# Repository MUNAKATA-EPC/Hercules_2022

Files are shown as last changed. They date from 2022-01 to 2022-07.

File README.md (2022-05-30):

# Hercules_2022

ヘラクレス2022シーズンのソースコード、基板データを公開しています。

詳しくはWikiを参照。

## 運用方針

- 大きな変更をするときはブランチを絶対に別途作成しましょう
- 小さな変更(スペルミスやコメント修正程度)ならどんどんmainブランチに突っ込んでもまあ構わないでしょう
- 余裕があったら変更した内容をコメントしてくれると助かります

## コードに関して

- 各プロジェクトフォルダの命名規則は「hogehoge(プロジェクト名)-teensy40(開発環境名)」となっていますが、一部試験用に作ったものに関しては、この命名規則が守られておりません...ごめんなさい。
- プロジェクトフォルダ内の「src」フォルダ内にmain.cpp(一部プロジェクトは名称が異なります)、「lib」フォルダ内に各種ライブラリ、「include」フォルダ内にサブプログラムが入っています。
- 一部PlatformIOからダウンロードしているライブラリが含まれているため、基本は「VSCode + PlatformIO」の組み合わせでご覧ください。

## 回路に関して

- 使用する設計ソフトにKiCad5と6が混在しています。
- ライブラリについてはLibraryフォルダを相対パスで参照しています。
- 発注は主にJLCPCBを使用します。

## 開発環境に関して

- VSCodeの拡張機能のPlatformIOを使用しTeensy 4.0とSeeeduino XIAOに書き込んでいます。
- 弊チームにはMacユーザーがいないため、Windows環境での開発を想定しております。Macをお使いの皆様、何か問題が生じても対応はできません。予めご了承ください。

## ライセンスに関して

- すべてのコード、基板データに関するライセンスはMITにしていますが、ライブラリ等のライセンスはそのライブラリごとのライセンスに従ってください。

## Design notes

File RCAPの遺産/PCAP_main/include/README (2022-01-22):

This directory is intended for project header files.

A header file is a file containing C declarations and macro definitions
to be shared between several project source files. You request the use of a
header file in your project source file (C, C++, etc) located in `src` folder
by including it, with the C preprocessing directive `#include'.

このディレクトリは、プロジェクトヘッダーファイル用です。

ヘッダーファイルは、C宣言とマクロ定義を含むファイルです。
複数のプロジェクトソースファイル間で共有されます。 あなたはの使用を要求します
`src`フォルダにあるプロジェクトソースファイル（C、C ++など）のヘッダーファイル
C前処理ディレクティブ `#include 'を使用してインクルードします。

```src/main.c

#include "header.h"

int main (void)
{
 ...
}
```
Including a header file produces the same results as copying the header file
into each source file that needs it. Such copying would be time-consuming
and error-prone. With a header file, the related declarations appear
in only one place. If they need to be changed, they can be changed in one
place, and programs that include the header file will automatically use the
new version when next recompiled. The header file eliminates the labor of
finding and changing all the copies as well as the risk that a failure to
find one copy will result in inconsistencies within a program.

ヘッダーファイルをインクルードすると、ヘッダーファイルをコピーした場合と同じ結果が得られます。
それを必要とする各ソースファイルに。 このようなコピーには時間がかかります
エラーが発生しやすい。 ヘッダーファイルを使用すると、関連する宣言が表示されます
一箇所だけで。 変更が必要な場合は、一度に変更できます
場所、およびヘッダーファイルを含むプログラムは自動的にを使用します
次に再コンパイルされたときの新しいバージョン。 ヘッダーファイルはの労力を排除します
すべてのコピーを見つけて変更するだけでなく、失敗するリスク
1つのコピーを見つけると、プログラム内で不整合が発生します。

In C, the usual convention is to give header files names that end with `.h'.
It is most portable to use only letters, digits, dashes, and underscores in
header file names, and at most one dot.

Cでは、通常の規則は、ヘッダーファイルに `.h 'で終わる名前を付けることです。
文字、数字、ダッシュ、およびアンダースコアのみを使用するのが最も移植性があります
ヘッダーファイル名、および最大1つのドット。

Read more about using header files in official GCC documentation:

* Include Syntax
* Include Operation
* Once-Only Headers
* Computed Includes

https://gcc.gnu.org/onlinedocs/cpp/Header-Files.html

s公式GCCドキュメントでヘッダーファイルの使用について詳しく読む：

*構文を含める
*操作を含める
* 1回限りのヘッダー
*計算されたインクルード

https://gcc.gnu.org/onlinedocs/cpp/Header-Files.html

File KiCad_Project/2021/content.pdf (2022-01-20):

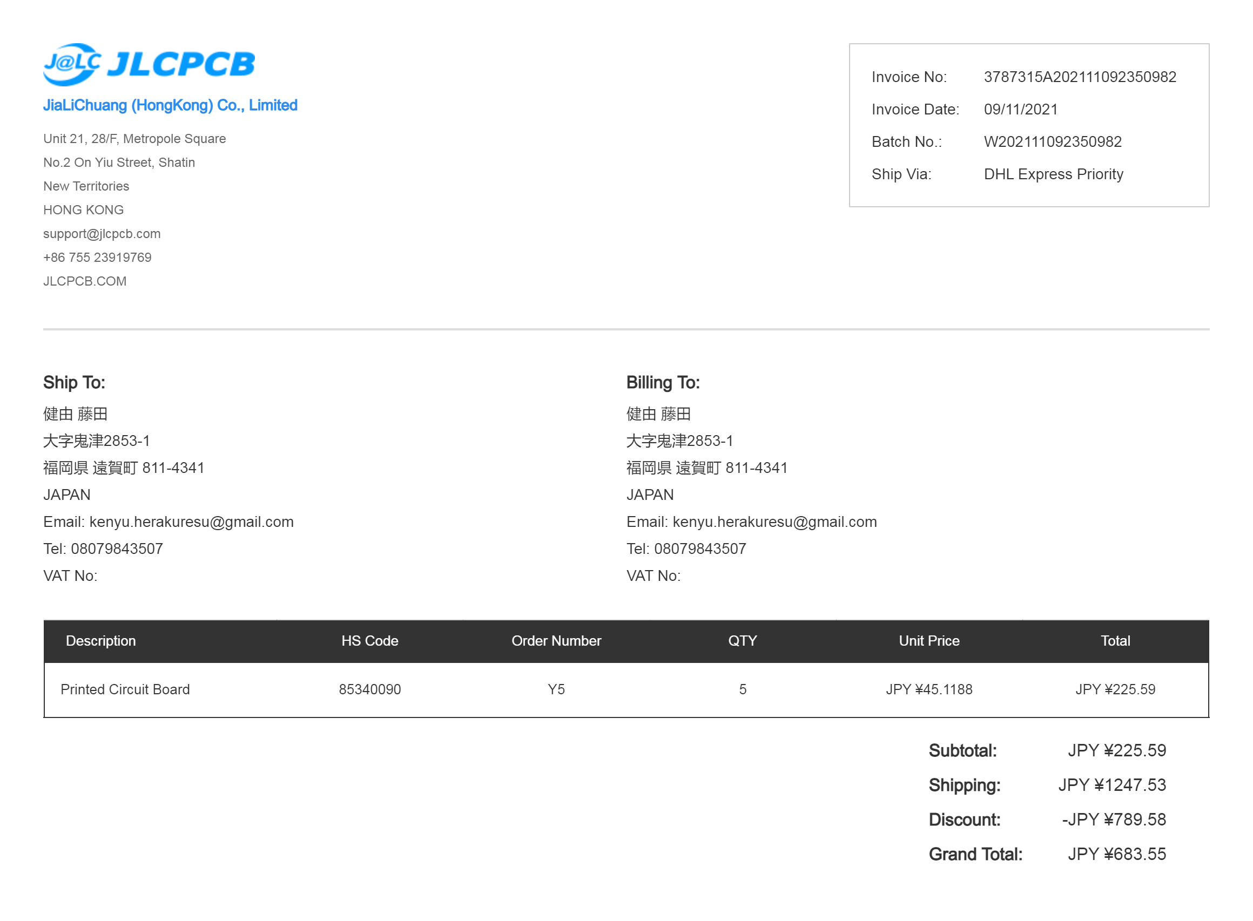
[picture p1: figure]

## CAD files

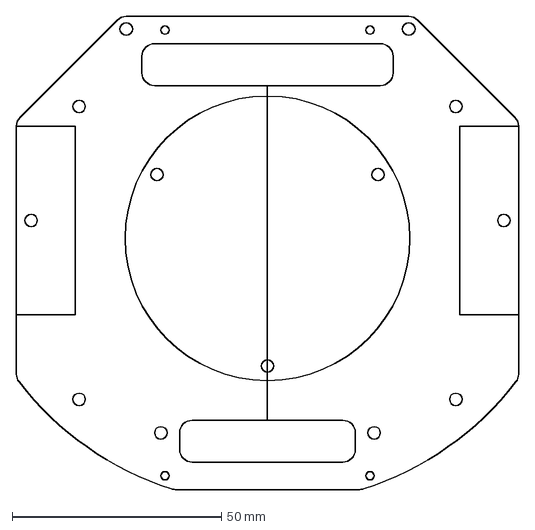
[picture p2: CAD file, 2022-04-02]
KiCad_Project/2022/DXF/Main_Board_2.dxf
120.0 x 113.0 mm

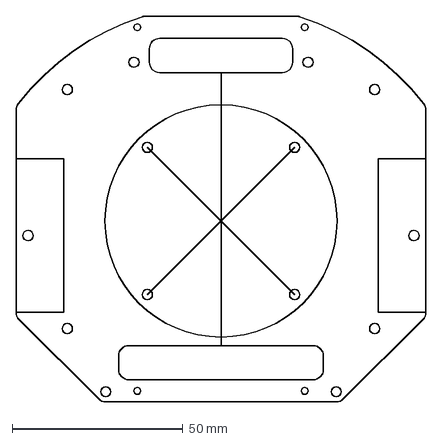
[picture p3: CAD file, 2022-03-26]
KiCad_Project/2022/DXF/Main_Board.dxf
120.0 x 113.0 mm

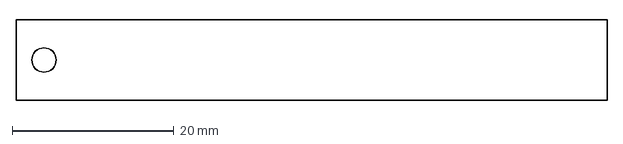
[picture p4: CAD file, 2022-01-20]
KiCad_Project/2021/DXF/LINE_2.dxf
73.0 x 10.0 mm

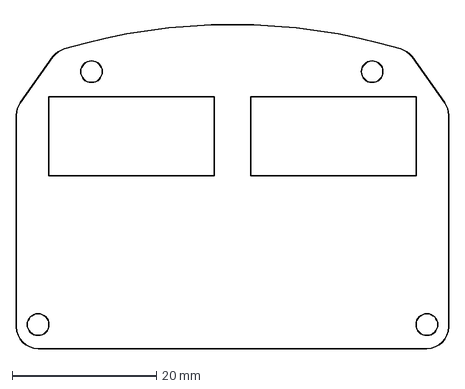
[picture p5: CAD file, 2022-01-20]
KiCad_Project/2021/電源基板.dxf
60.0 x 46.1 mm

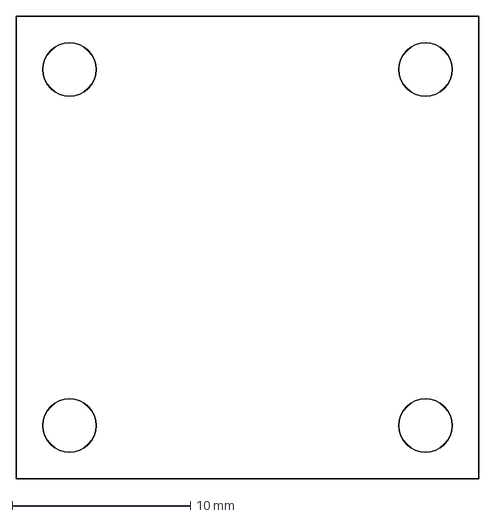
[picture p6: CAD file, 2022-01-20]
KiCad_Project/2021/DXF/LINE_1.dxf
26.0 x 26.0 mm

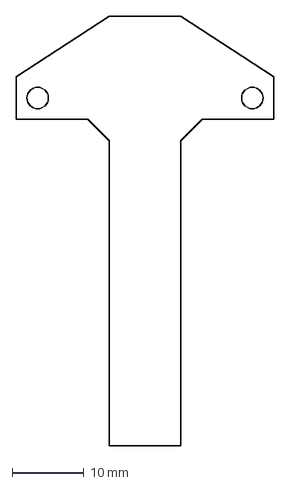
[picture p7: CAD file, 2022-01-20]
KiCad_Project/2021/DXF/LINE_4.dxf
36.0 x 60.0 mm

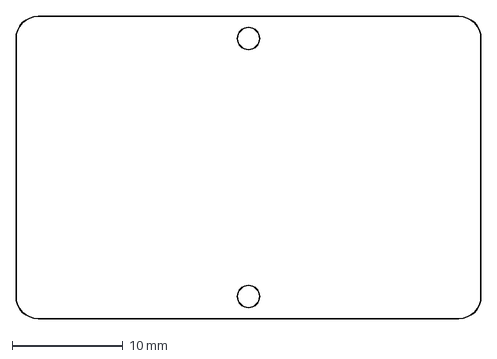
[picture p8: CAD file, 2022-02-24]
KiCad_Project/2022/DXF/ADNS-9800.dxf
42.0 x 27.3 mm

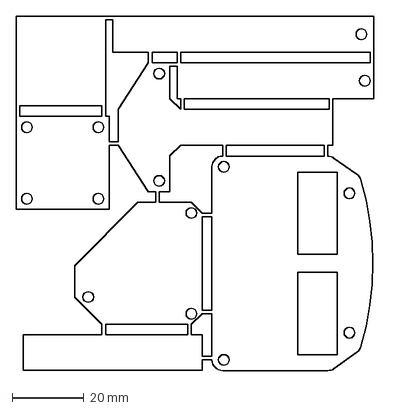
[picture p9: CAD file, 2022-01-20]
KiCad_Project/2021/DXF/発注基板 v1.dxf
100.9 x 99.1 mm

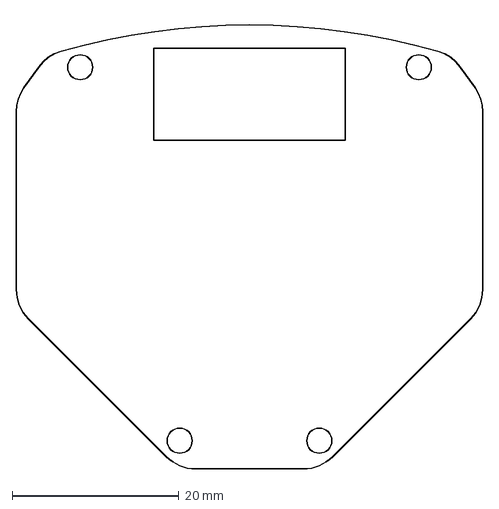
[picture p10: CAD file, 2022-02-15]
KiCad_Project/2022/DXF/Integrated_Power_Board.dxf
56.0 x 54.4 mm

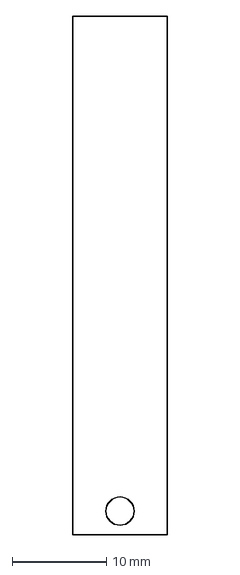
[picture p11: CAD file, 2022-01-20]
KiCad_Project/2021/DXF/LINE_3.dxf
10.0 x 55.0 mm

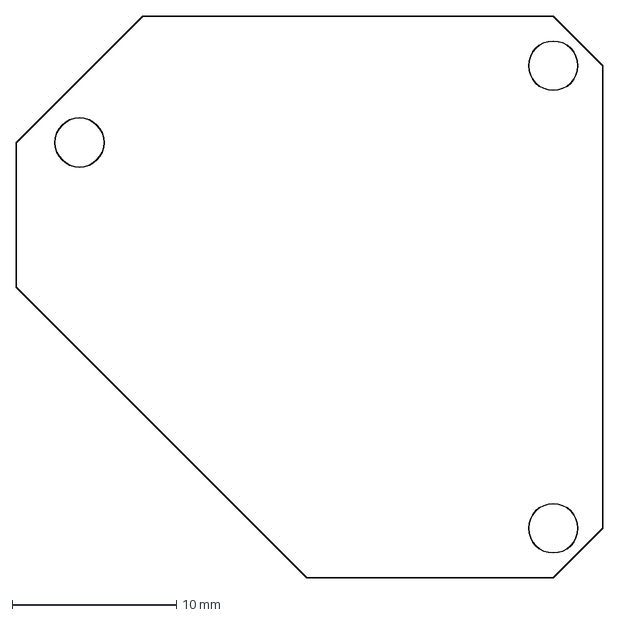
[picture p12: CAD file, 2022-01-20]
KiCad_Project/2021/DXF/kick.dxf
35.7 x 34.2 mm

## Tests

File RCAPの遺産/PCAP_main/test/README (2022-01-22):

This directory is intended for PlatformIO Unit Testing and project tests.

Unit Testing is a software testing method by which individual units of
source code, sets of one or more MCU program modules together with associated
control data, usage procedures, and operating procedures, are tested to
determine whether they are fit for use. Unit testing finds problems early
in the development cycle.

このディレクトリは、PlatformIOユニットテストおよびプロジェクトテストを対象としています。
ユニットテストは、ソースコードの個々のユニット、関連する制御データ、使用手順、および操作手順とともに1つ以上のMCUプログラムモジュールのセットによるソフトウェアテスト方法であり、
それらが使用に適しているかどうかを判断するためにテストされます。 
単体テストでは、開発サイクルの早い段階で問題が見つかります。

More information about PlatformIO Unit Testing:
- https://docs.platformio.org/page/plus/unit-testing.html

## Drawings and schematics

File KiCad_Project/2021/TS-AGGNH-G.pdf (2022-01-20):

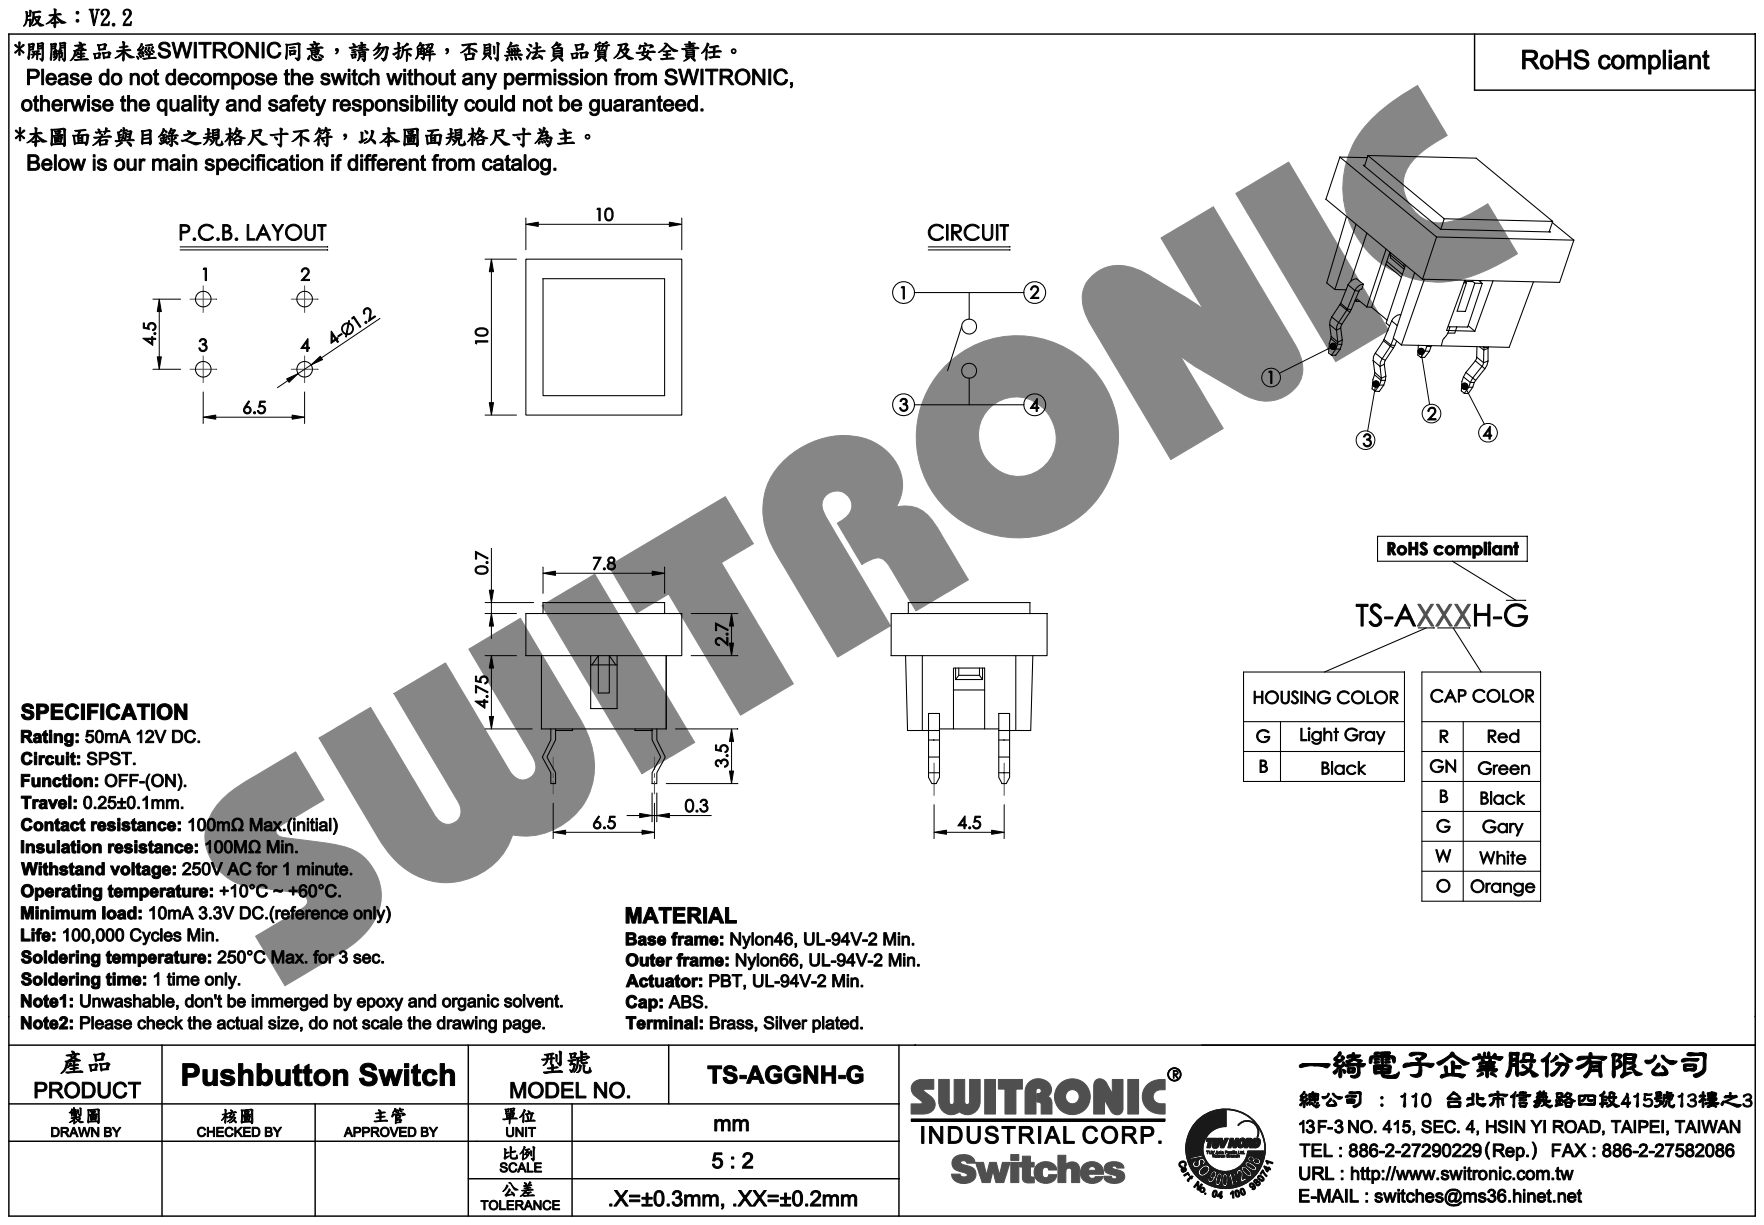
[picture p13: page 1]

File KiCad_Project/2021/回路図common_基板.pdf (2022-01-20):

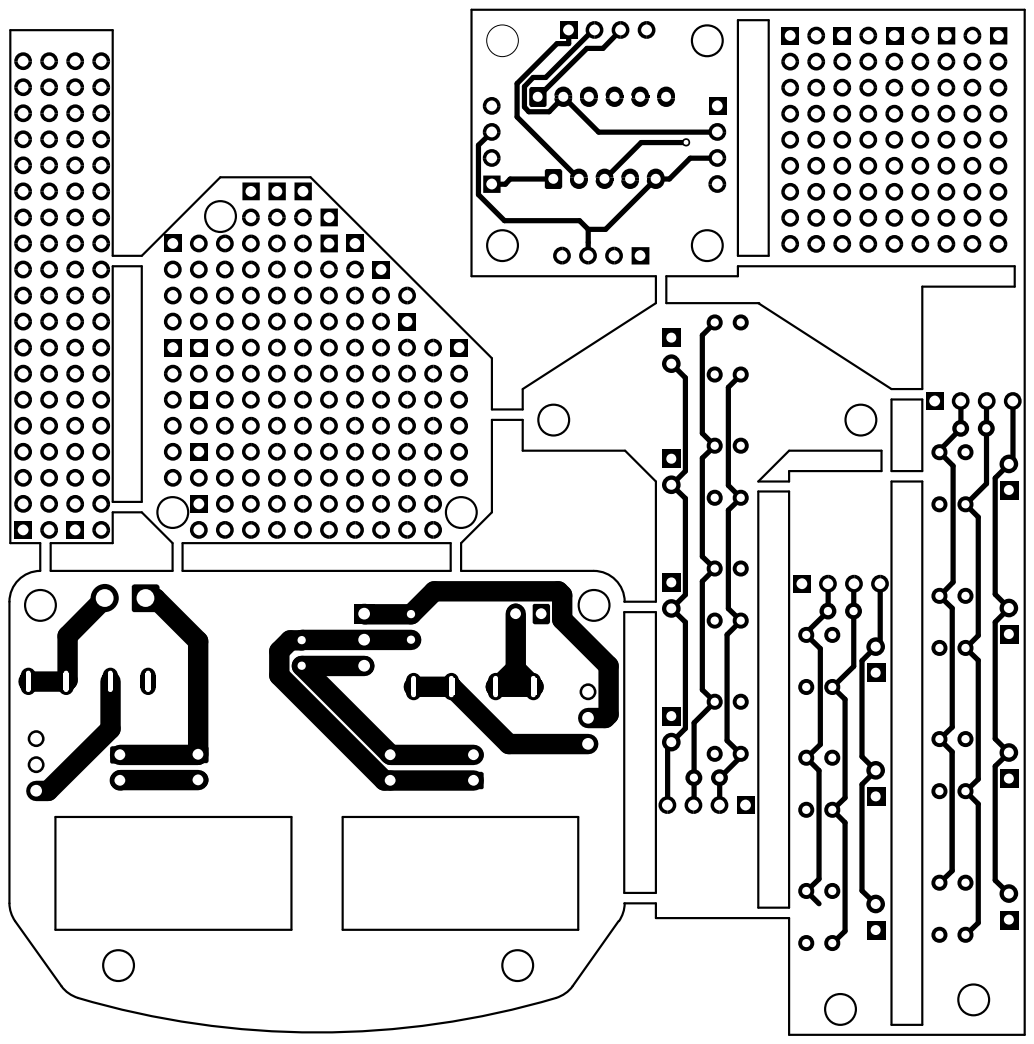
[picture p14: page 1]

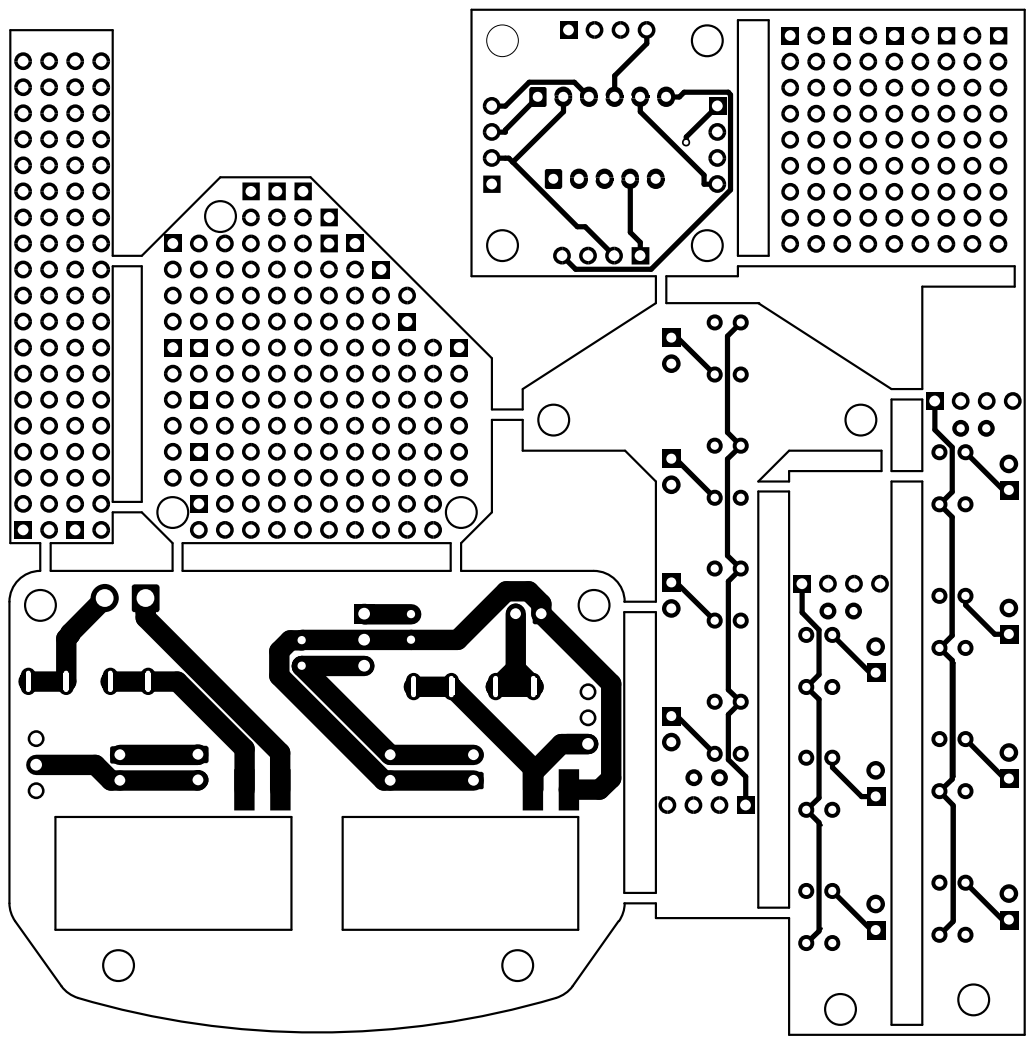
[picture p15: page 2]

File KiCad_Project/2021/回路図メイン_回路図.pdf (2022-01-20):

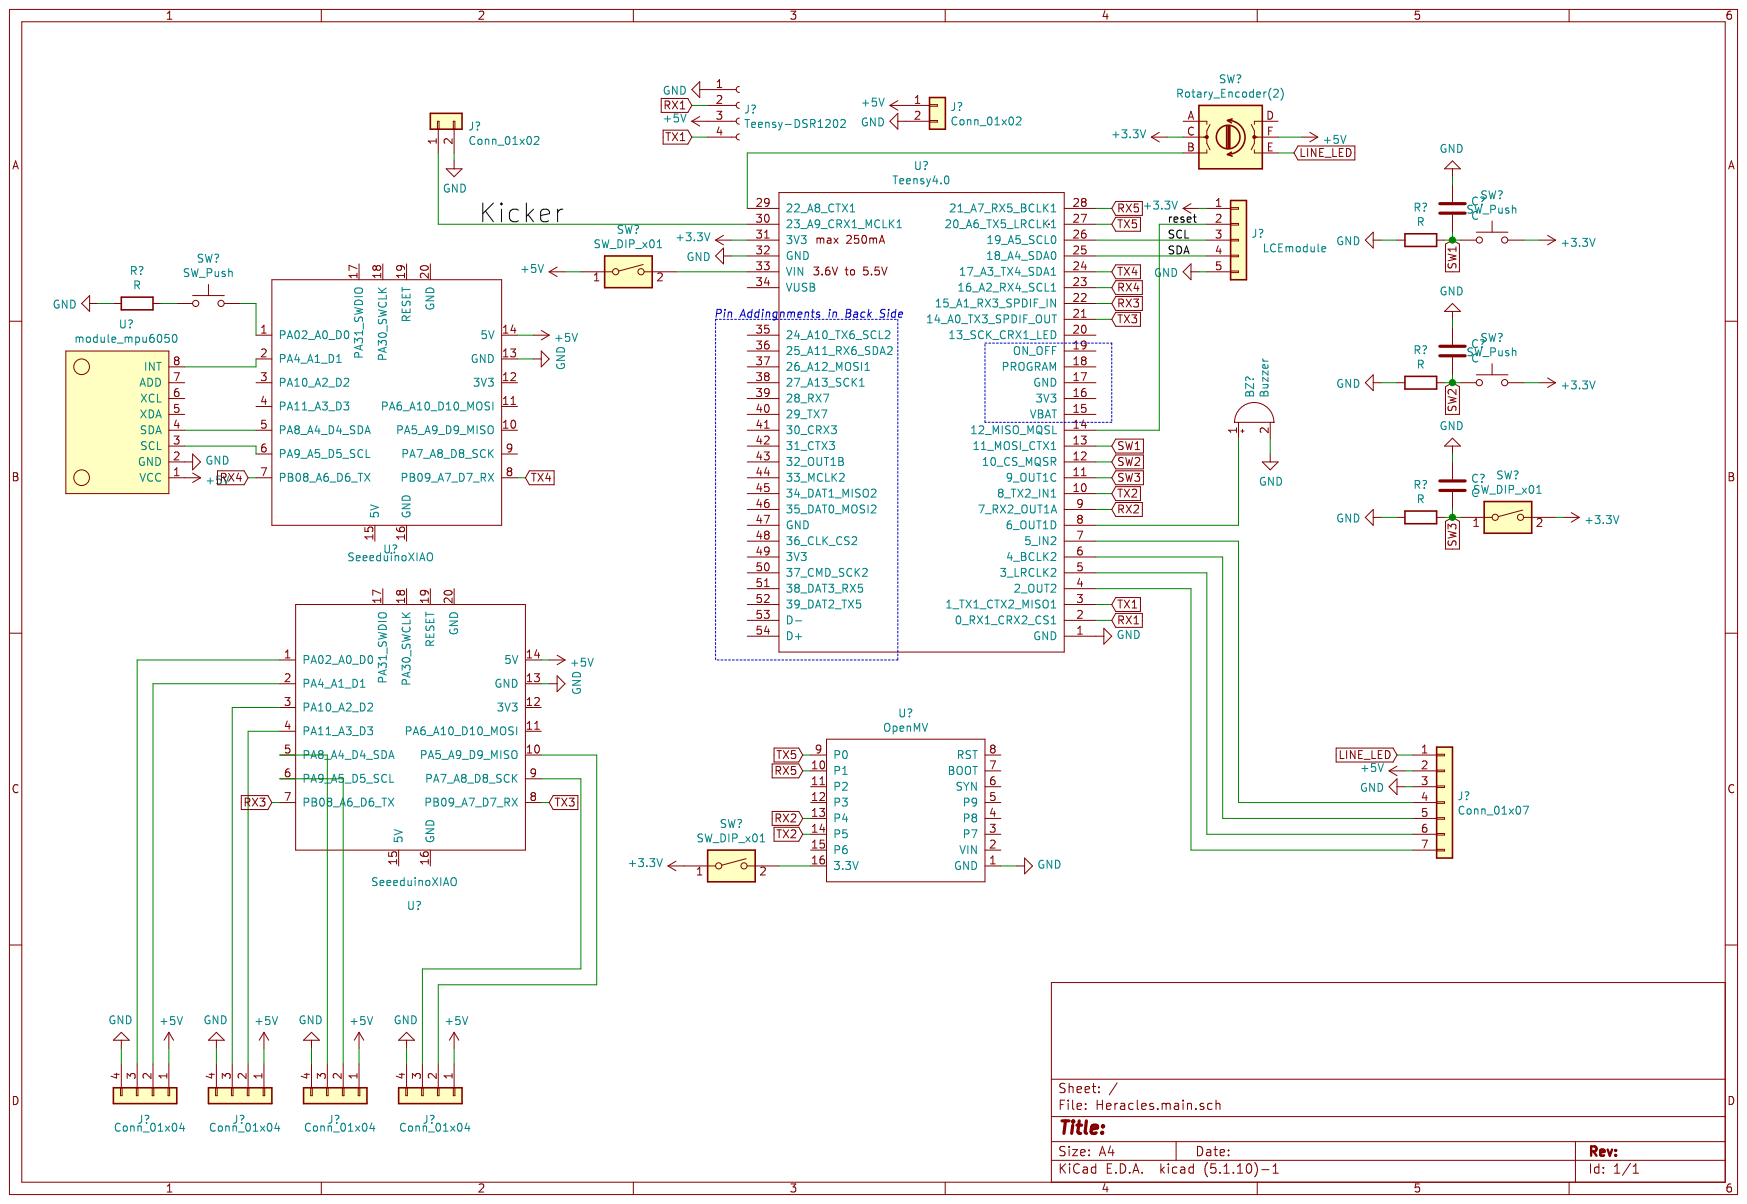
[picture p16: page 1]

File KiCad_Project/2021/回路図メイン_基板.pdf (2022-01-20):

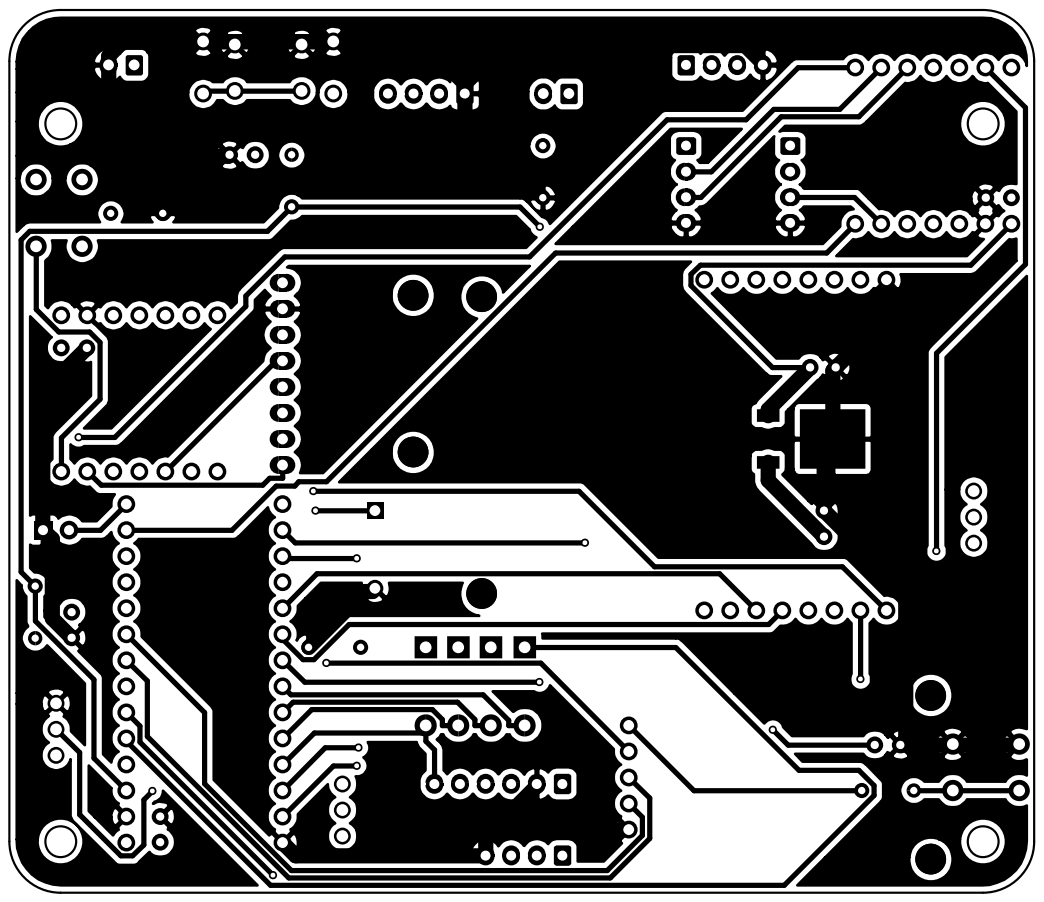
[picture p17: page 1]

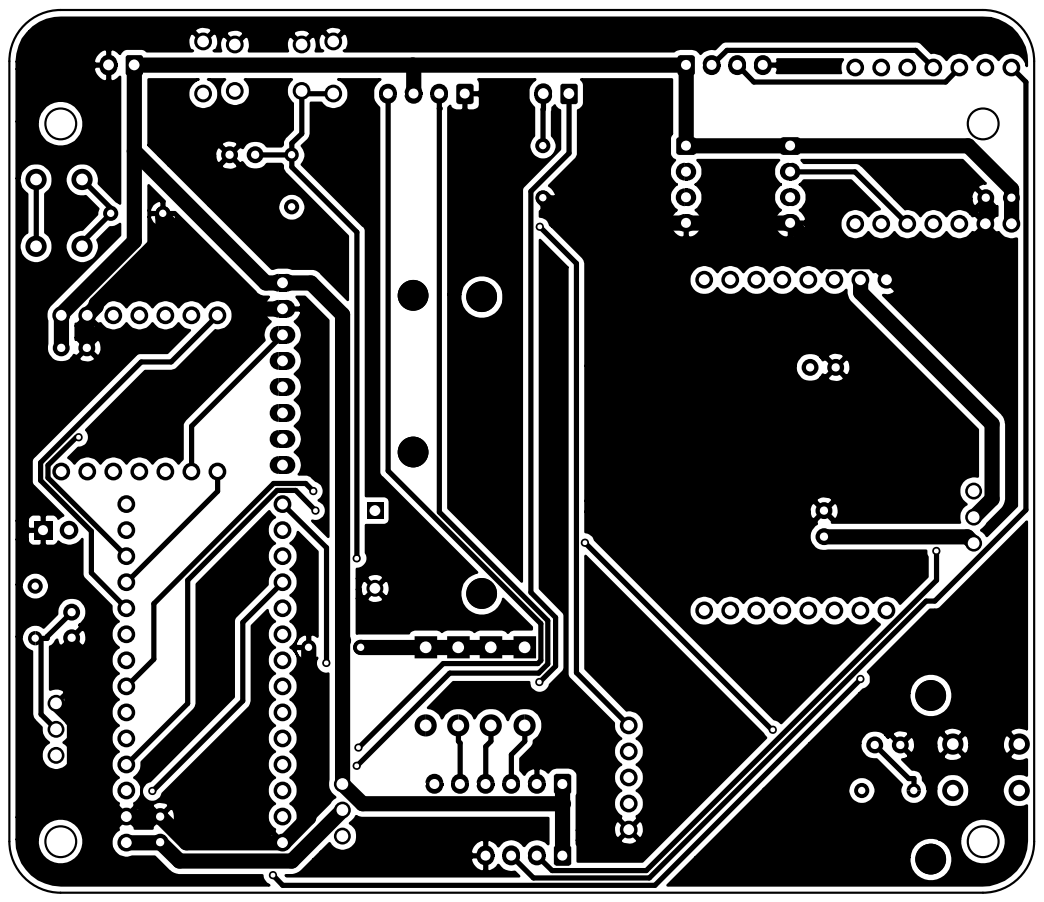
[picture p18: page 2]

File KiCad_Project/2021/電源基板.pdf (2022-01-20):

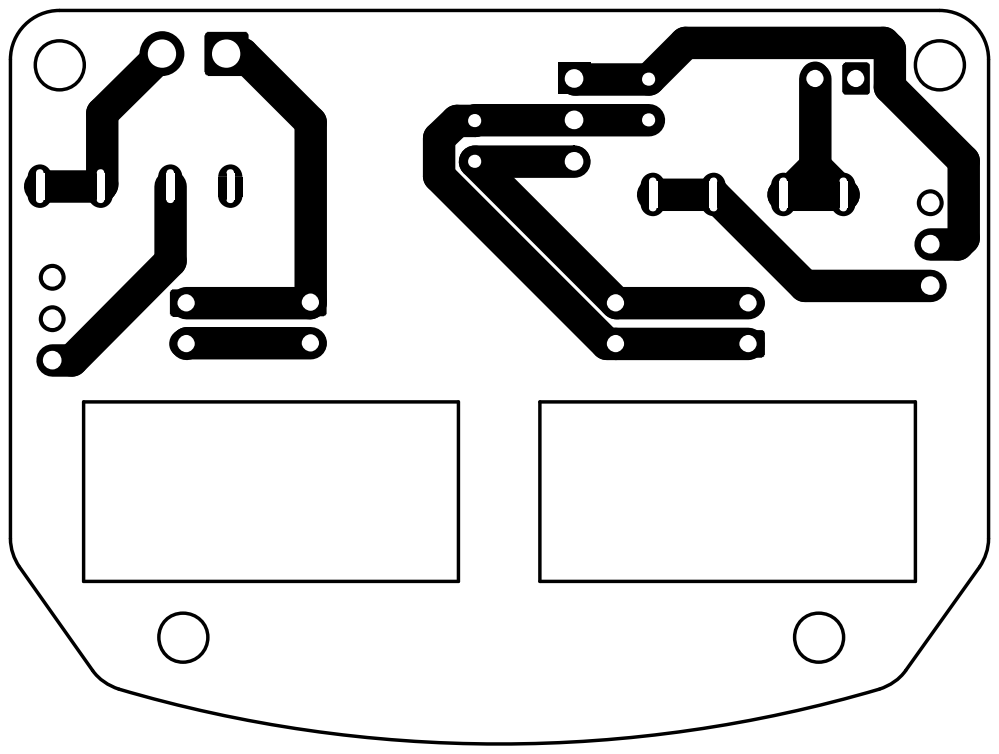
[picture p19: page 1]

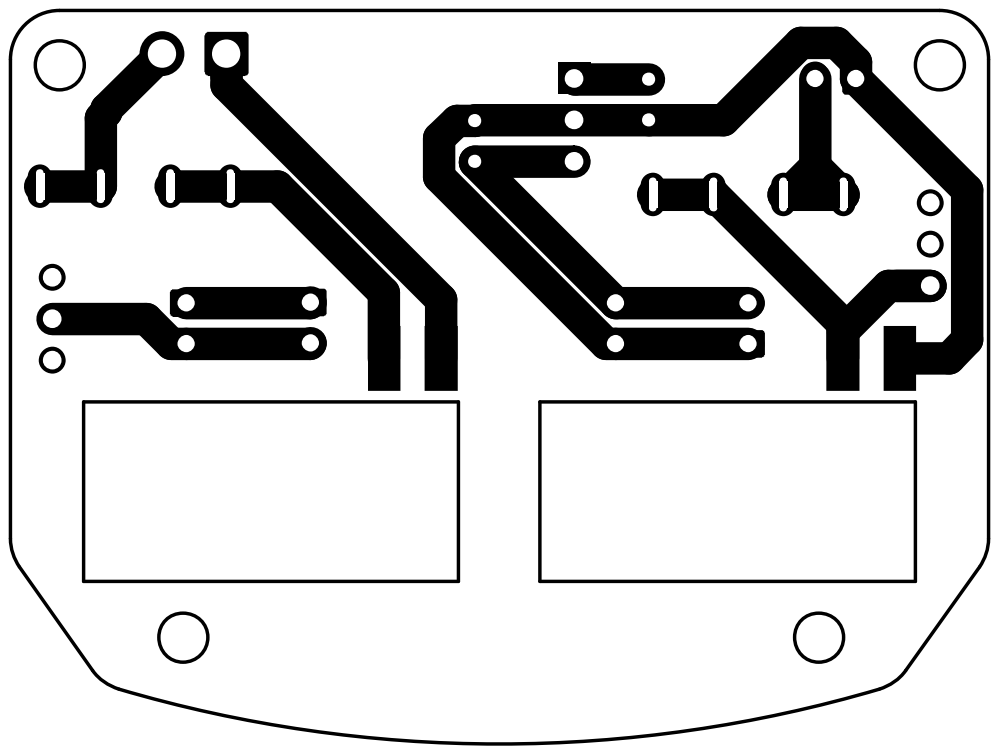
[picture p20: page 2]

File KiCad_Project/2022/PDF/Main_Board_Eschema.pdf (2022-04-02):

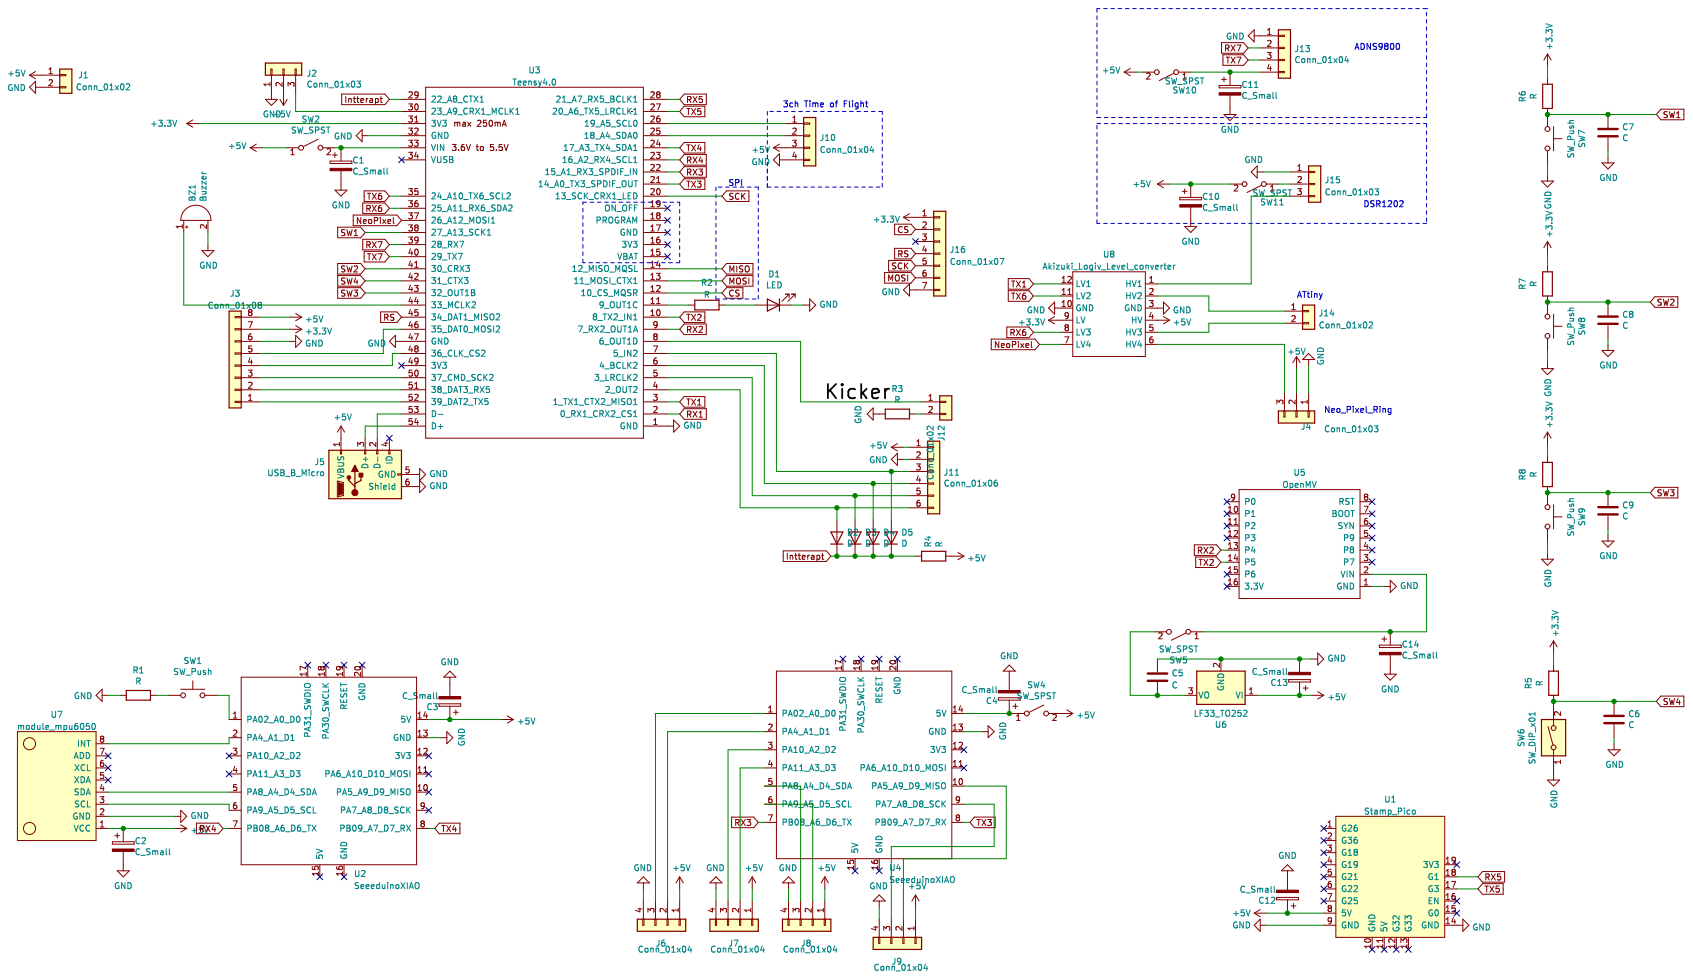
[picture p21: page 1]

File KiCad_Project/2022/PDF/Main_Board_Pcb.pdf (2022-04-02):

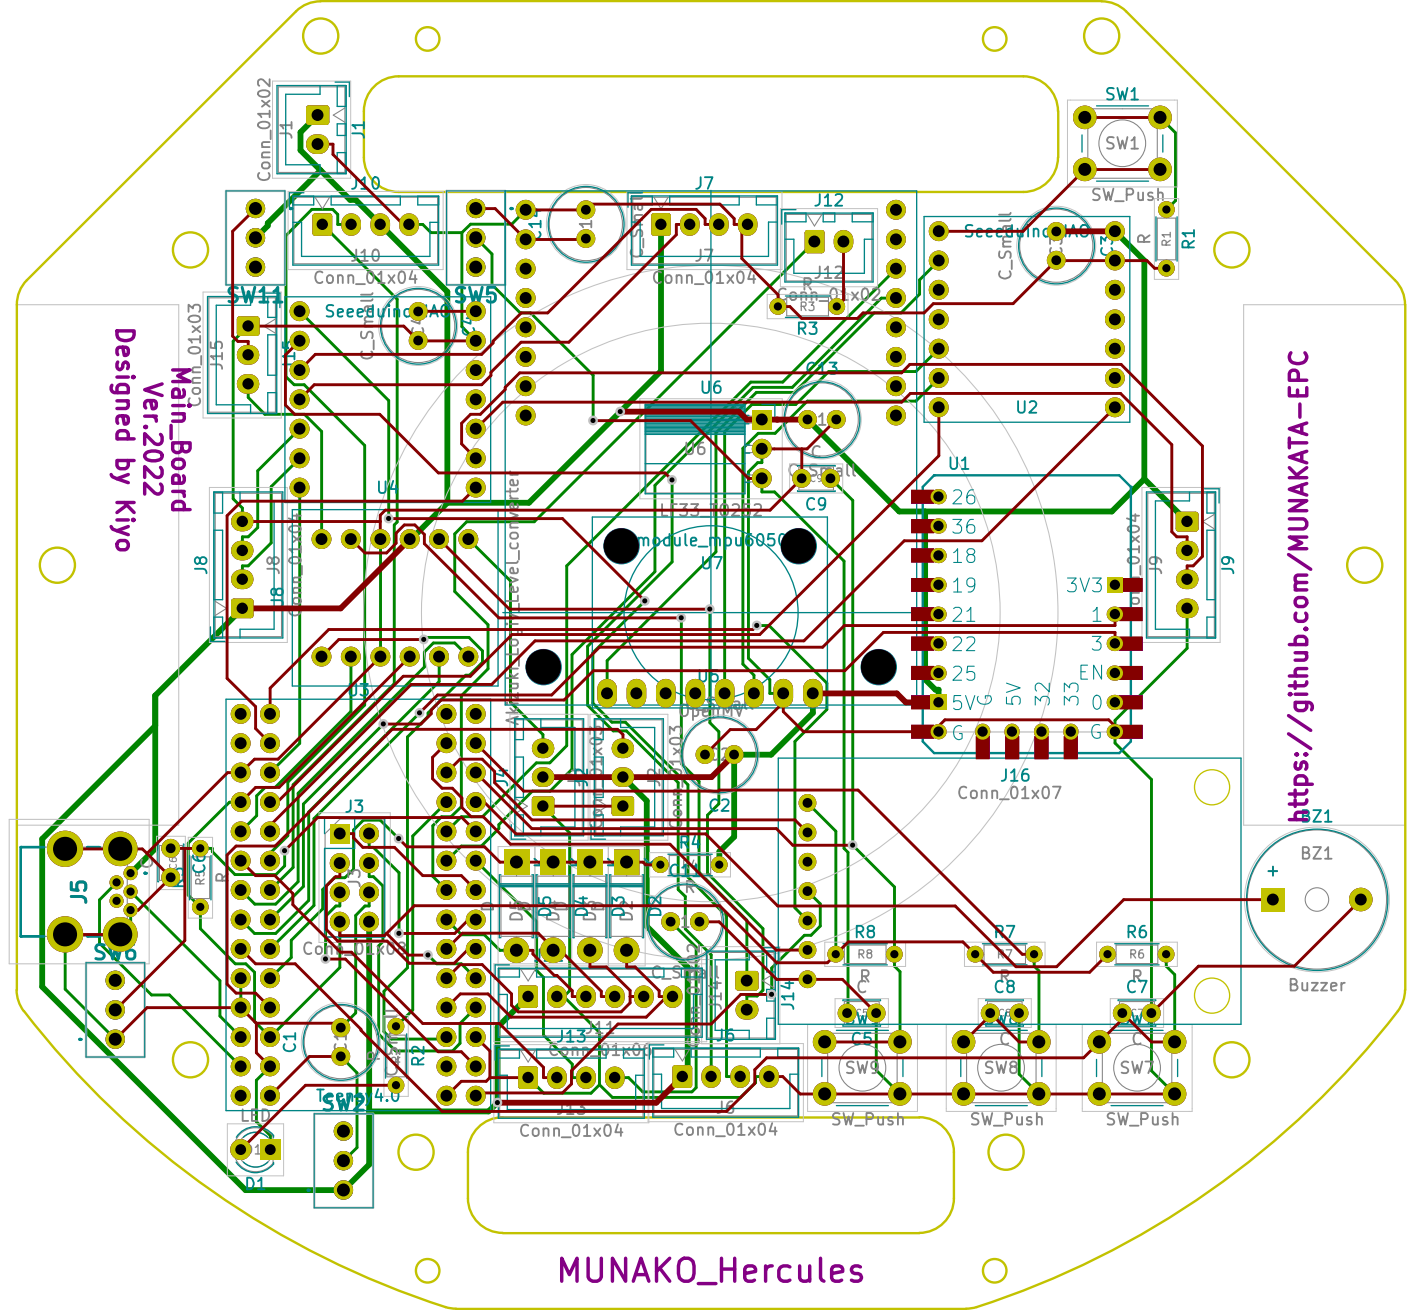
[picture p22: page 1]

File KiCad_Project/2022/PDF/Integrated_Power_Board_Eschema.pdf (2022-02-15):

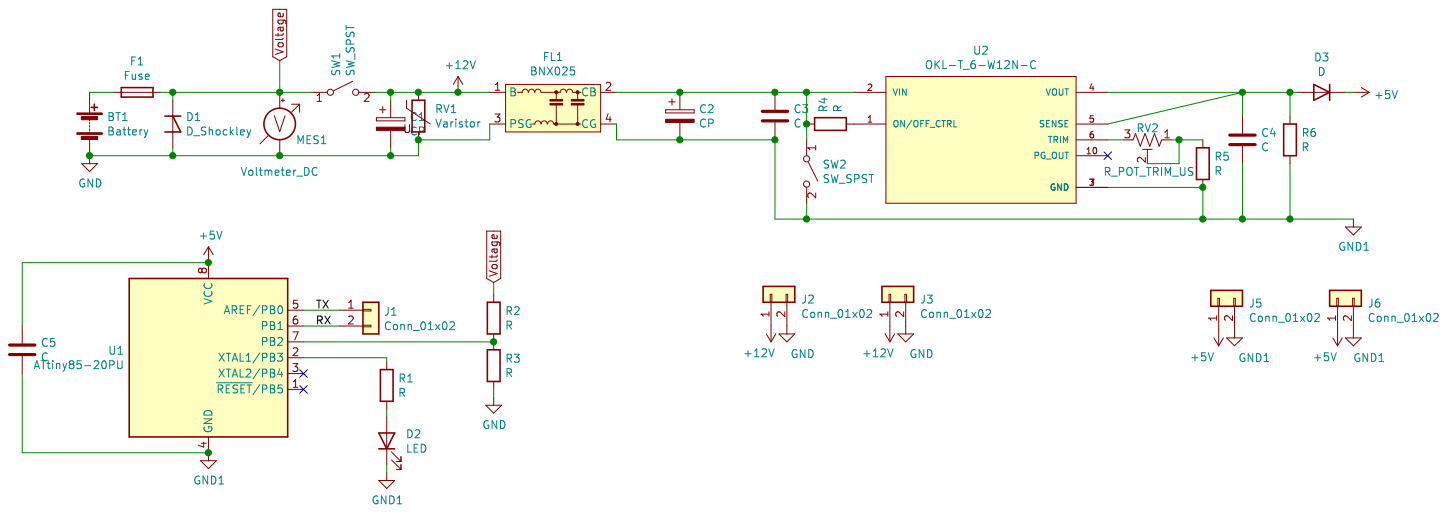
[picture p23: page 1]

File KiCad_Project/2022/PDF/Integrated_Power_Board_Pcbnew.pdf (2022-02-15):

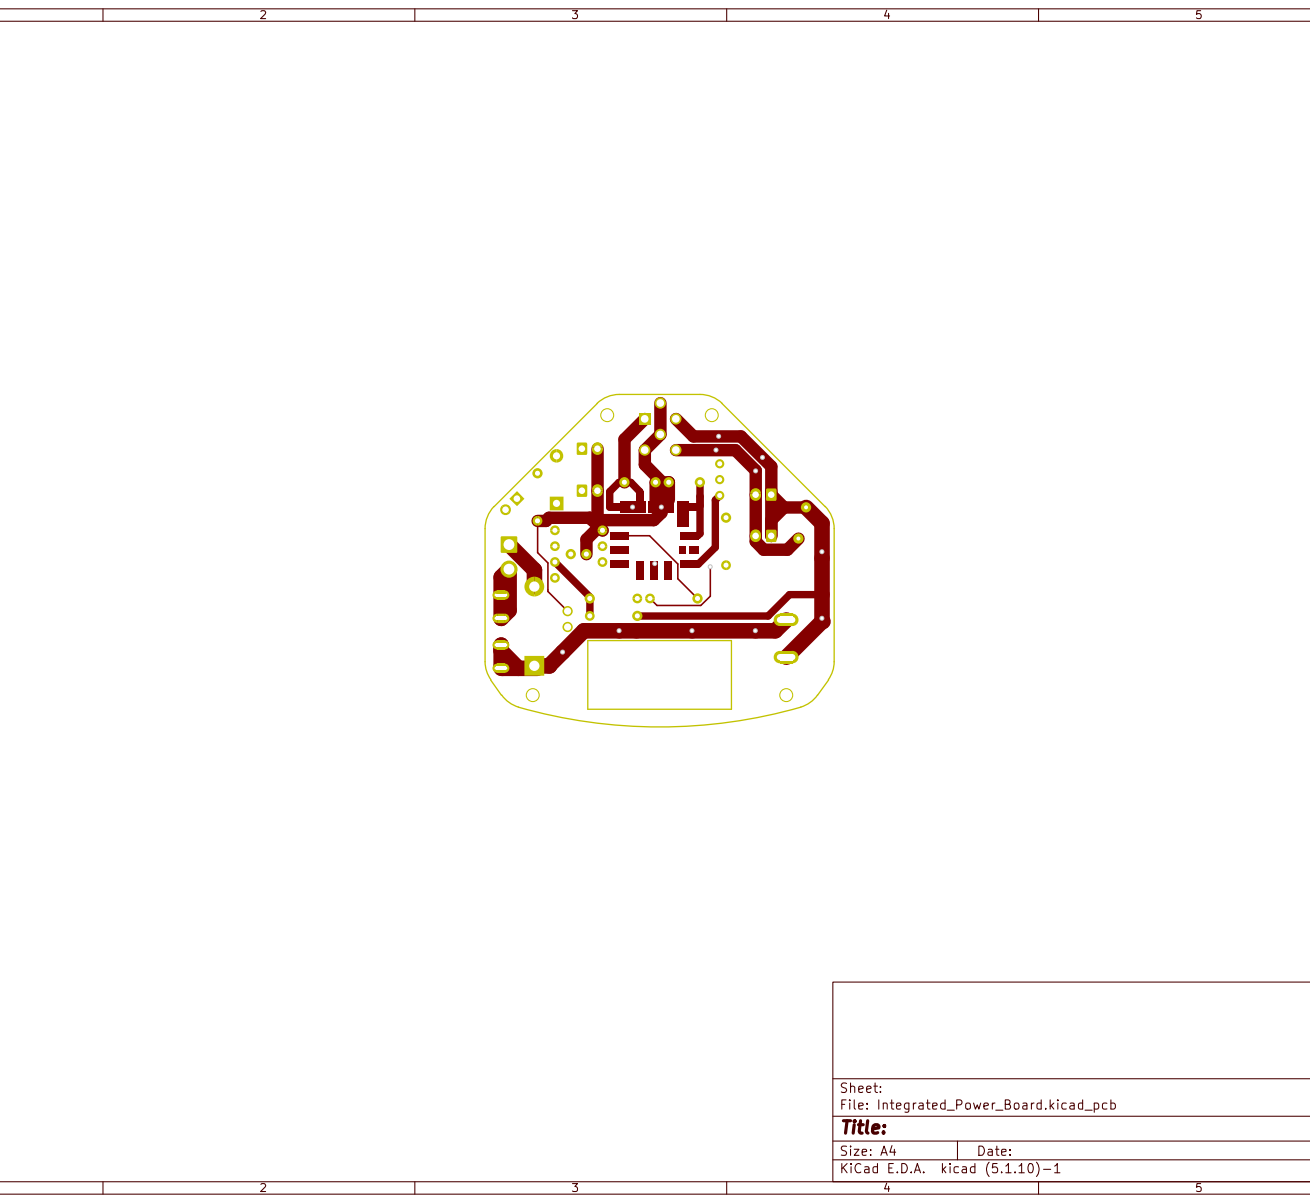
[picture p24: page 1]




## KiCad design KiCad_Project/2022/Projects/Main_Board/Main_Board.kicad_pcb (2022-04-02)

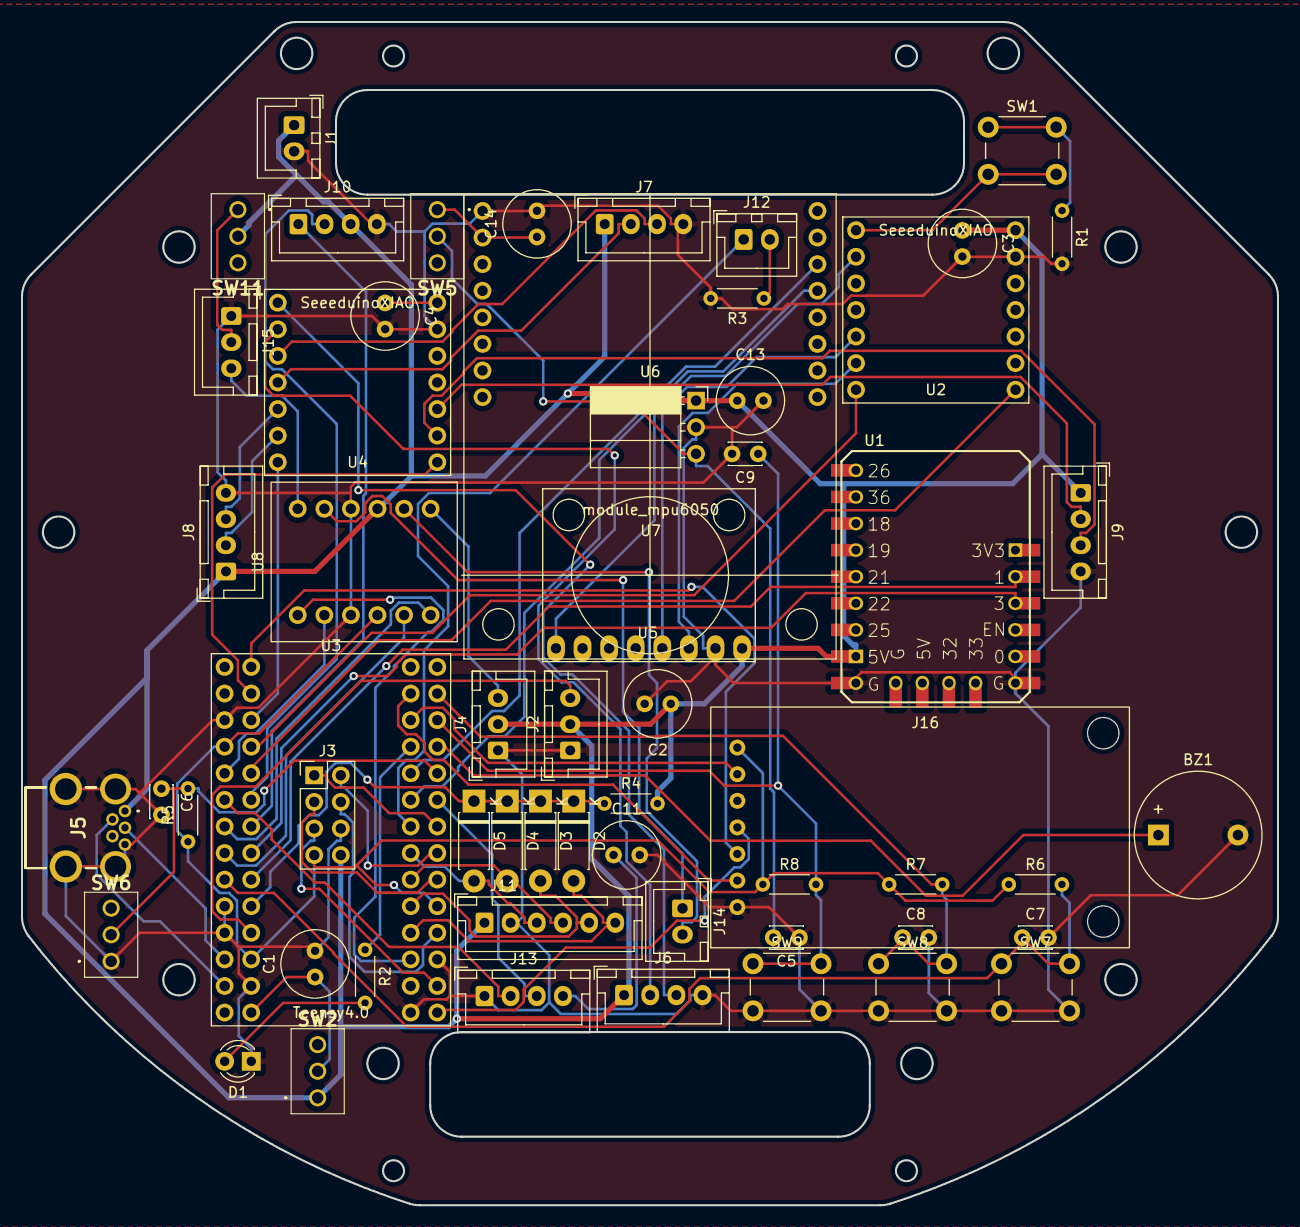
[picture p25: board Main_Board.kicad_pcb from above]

Board: 2 copper layers, 120.0 x 113.0 mm, 58 parts (0 on the bottom side), 68 nets.

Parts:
BZ1: Buzzer; Buzzer_12x9.5RM7.6
C1, C2, C3, C4, C11, C13, C14: C_Small; C_Radial_D6.3mm_H11.0mm_P2.50mm
C5, C6, C7, C8, C9: C; C_Disc_D3.0mm_W2.0mm_P2.50mm
D1: LED; LED_D3.0mm_Clear
D2, D3, D4, D5: D; D_DO-41_SOD81_P7.62mm_Horizontal
J1, J12, J14: Conn_01x02; JST_XH_B2B-XH-A_1x02_P2.50mm_Vertical
J2, J4, J15: Conn_01x03; JST_XH_B3B-XH-A_1x03_P2.50mm_Vertical
J3: Conn_01x08; PinHeader_2x04_P2.54mm_Vertical
J5: USB_B_Micro; MUSB5BF01AS
J6, J7, J8, J9, J10, J13: Conn_01x04; JST_XH_B4B-XH-A_1x04_P2.50mm_Vertical
J11: Conn_01x06; JST_XH_B6B-XH-A_1x06_P2.50mm_Vertical
J16: Conn_01x07; LCD
R1, R2, R3, R4, R5, R6, R7, R8: R; R_Axial_DIN0204_L3.6mm_D1.6mm_P5.08mm_Horizontal
SW1, SW7, SW8, SW9: SW_Push; SW_PUSH_6mm_H5mm
SW2, SW5, SW11: SW_SPST; toggleswitch
SW6: SW_DIP_x01; toggleswitch
U1: Stamp_Pico; StampPico_template
U2, U4: SeeeduinoXIAO; seeeduinoXIAO
U3: Teensy4.0; Teensy
U5: OpenMV
U6: LF33_TO252; PinSocket_1x03_P2.54mm_Horizontal
U7: module_mpu6050; MPU6050
U8: Akizuki_Logiv_Level_converter; Akizuki_Logic_Level_converter

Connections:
+3V3: J3.7, J16.1, R5.1, R6.1, R7.1, R8.1, U3.31 (3V3), U8.9 (LV)
+5V: C2.1, C3.1, C13.1, J1.1, J2.2, J3.8, J4.2, J5.1 (VBUS), J6.1, J7.1, J8.1, J9.1, J10.3, J11.1, R4.2, SW2.1 (A), SW11.2 (B), U1.8 (5V), U2.14 (5V), U6.1 (VI), U7.1 (VCC), U8.4 (HV)
/Kicker: J12.1, U3.8 (6_OUT1D)
CS: J16.2, U3.12 (10_CS_MQSR)
GND: BZ1.2 (+), C1.2, C2.2, C3.2, C4.2, C5.1, C6.2, C7.2, C8.2, C9.2, C11.2, C13.2, C14.2, D1.1 (K), J1.2, J2.1, J3.6, J4.1, J5.5 (GND), J6.4, J7.4, J8.4, J9.4, J10.4, J11.2, J13.1, J15.1, J16.7, R1.2, R3.2, SW6.1, SW7.2, SW8.2, SW9.2, U1.9 (GND), U1.14 (GND), U2.13 (GND), U3.1 (GND), U4.13 (GND), U5.1 (GND), U6.2 (GND), U7.2 (GND), U8.3 (GND), U8.10 (GND)
Intterapt: D2.1 (K), D3.1 (K), D4.1 (K), D5.1 (K), R4.1, U3.29 (22_A8_CTX1)
MOSI: J16.6, U3.13 (11_MOSI_CTX1)
NeoPixel: U3.37 (26_A12_MOSI1), U8.7 (LV4)
unnamed: BZ1.1 (-), U3.44 (33_MCLK2)
unnamed: C1.1, SW2.2 (B), U3.33 (VIN)
unnamed: C4.1, U4.14 (5V)
unnamed: C5.2, SW5.2 (B), U6.3 (VO)
unnamed: C11.1, J13.4
unnamed: C14.1, SW5.1 (A), U5.2 (VIN)
unnamed: D1.2 (A), R2.2
unnamed: D2.2 (A), J11.6, U3.4 (2_OUT2)
unnamed: D3.2 (A), J11.5, U3.5 (3_LRCLK2)
unnamed: D4.2 (A), J11.4, U3.6 (4_BCLK2)
unnamed: D5.2 (A), J11.3, U3.7 (5_IN2)
unnamed: J2.3, U3.30 (23_A9_CRX1_MCLK1)
unnamed: J3.1, U3.52 (39_DAT2_TX5)
unnamed: J3.2, U3.51 (38_DAT3_RX5)
unnamed: J3.3, U3.50 (37_CMD_SCK2)
unnamed: J3.4, U3.48 (36_CLK_CS2)
unnamed: J3.5, U3.46 (35_DAT0_MOSI2)
unnamed: J4.3, U8.6 (HV4)
unnamed: J5.2 (D-), U3.53 (D-)
unnamed: J5.3 (D+), U3.54 (D+)
unnamed: J6.2, U4.2 (PA4_A1_D1)
unnamed: J6.3, U4.1 (PA02_A0_D0)
unnamed: J7.2, U4.4 (PA11_A3_D3)
unnamed: J7.3, U4.3 (PA10_A2_D2)
unnamed: J8.2, U4.6 (PA9_A5_D5_SCL)
unnamed: J8.3, U4.5 (PA8_A4_D4_SDA)
unnamed: J9.2, U4.10 (PA5_A9_D9_MISO)
unnamed: J9.3, U4.9 (PA7_A8_D8_SCK)
unnamed: J10.1, U3.26 (19_A5_SCL0)
unnamed: J10.2, U3.25 (18_A4_SDA0)
unnamed: J12.2, R3.1
unnamed: J14.1, U8.2 (HV2)
unnamed: J14.2, U8.5 (HV3)
unnamed: J15.2, SW11.1 (A)
unnamed: J15.3, U8.1 (HV1)
unnamed: R1.1, SW1.1
unnamed: R2.1, U3.11 (9_OUT1C)
unnamed: SW1.2, U2.1 (PA02_A0_D0)
unnamed: U2.2 (PA4_A1_D1), U7.8 (INT)
unnamed: U2.5 (PA8_A4_D4_SDA), U7.4 (SDA)
unnamed: U2.6 (PA9_A5_D5_SCL), U7.3 (SCL)
RS: J16.4, U3.45 (34_DAT1_MISO2)
RX2: U3.9 (7_RX2_OUT1A), U5.13 (P4)
RX3: U3.22 (15_A1_RX3_SPDIF_IN), U4.7 (PB08_A6_D6_TX)
RX4: U2.7 (PB08_A6_D6_TX), U3.23 (16_A2_RX4_SCL1)
RX5: U1.18 (G1), U3.28 (21_A7_RX5_BCLK1)
RX6: U3.36 (25_A11_RX6_SDA2), U8.8 (LV3)
RX7: J13.2, U3.39 (28_RX7)
SCK: J16.5, U3.20 (13_SCK_CRX1_LED)
SW1: C7.1, R6.2, SW7.1, U3.38 (27_A13_SCK1)
SW2: C8.1, R7.2, SW8.1, U3.41 (30_CRX3)
SW3: C9.1, R8.2, SW9.1, U3.43 (32_OUT1B)
SW4: C6.1, R5.2, SW6.2, U3.42 (31_CTX3)
TX1: U3.3 (1_TX1_CTX2_MISO1), U8.12 (LV1)
TX2: U3.10 (8_TX2_IN1), U5.14 (P5)
TX3: U3.21 (14_A0_TX3_SPDIF_OUT), U4.8 (PB09_A7_D7_RX)
TX4: U2.8 (PB09_A7_D7_RX), U3.24 (17_A3_TX4_SDA1)
TX5: U1.17 (G3), U3.27 (20_A6_TX5_LRCLK1)
TX6: U3.35 (24_A10_TX6_SCL2), U8.11 (LV2)
TX7: J13.3, U3.40 (29_TX7)

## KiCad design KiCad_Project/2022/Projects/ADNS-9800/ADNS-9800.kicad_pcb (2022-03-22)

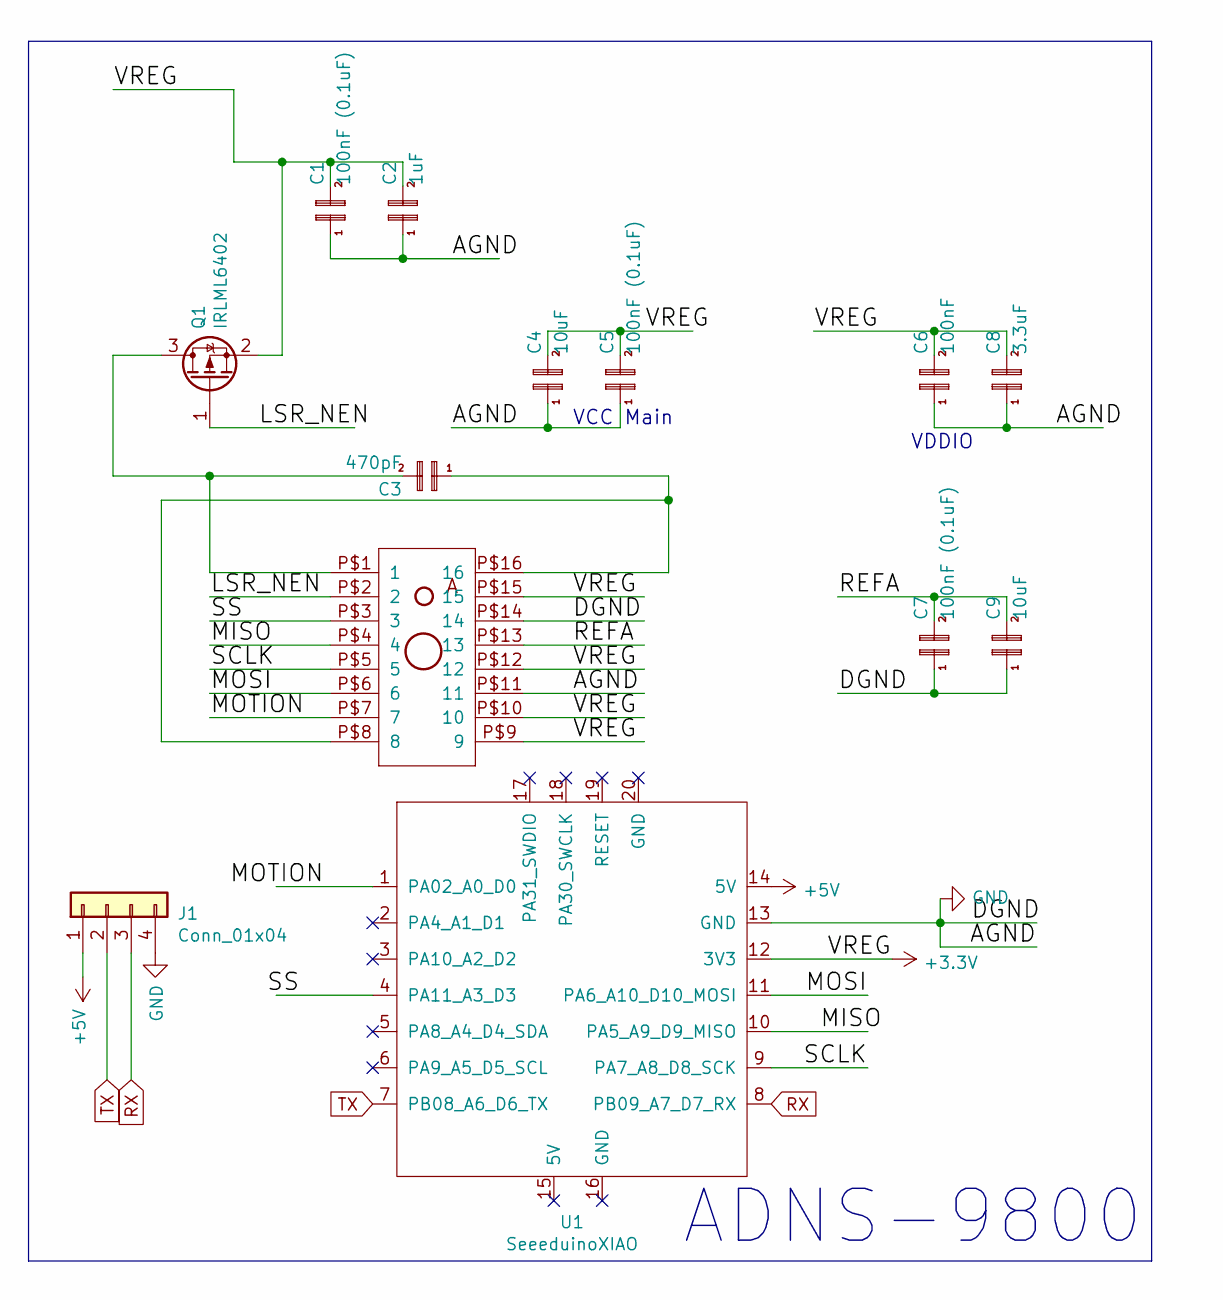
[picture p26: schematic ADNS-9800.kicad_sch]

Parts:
C1, C5, C7: 100nF (0.1uF); C_0603_1608Metric_Pad1.08x0.95mm_HandSolder
C2: 1uF; C_0603_1608Metric_Pad1.08x0.95mm_HandSolder
C3: 470pF; C_0603_1608Metric_Pad1.08x0.95mm_HandSolder
C4, C9: 10uF; C_0603_1608Metric_Pad1.08x0.95mm_HandSolder
C6: 100nF; C_0603_1608Metric_Pad1.08x0.95mm_HandSolder
C8: 3.3uF; C_0603_1608Metric_Pad1.08x0.95mm_HandSolder
J1: Conn_01x04; JST_XH_S4B-XH-A_1x04_P2.50mm_Horizontal
Q1: IRLML6402; SOT-23
U1: SeeeduinoXIAO; Seeeduino XIAO-MOUDLE14P-2.54-21X17.8MM
U$1: AVAGO_ADNS-9500

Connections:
+3V3: C1.2, C2.2, C4.2, C5.2, C6.2, C8.2, Q1.2 (S), U1.12 (3V3), U$1.P$9 (9), U$1.P$10 (10), U$1.P$12 (12), U$1.P$15 (15)
+5V: J1.1, U1.14 (5V)
/LSR_NEN: Q1.1 (G), U$1.P$2 (2)
/MISO: U1.10 (PA5_A9_D9_MISO), U$1.P$4 (4)
/MOSI: U1.11 (PA6_A10_D10_MOSI), U$1.P$6 (6)
/MOTION: U1.1 (PA02_A0_D0), U$1.P$7 (7)
/REFA: C7.2, C9.2, U$1.P$13 (13)
/SCLK: U1.9 (PA7_A8_D8_SCK), U$1.P$5 (5)
/SS: U1.4 (PA11_A3_D3), U$1.P$3 (3)
GND: C1.1, C2.1, C4.1, C5.1, C6.1, C7.1, C8.1, C9.1, J1.4, U1.13 (GND), U$1.P$11 (11), U$1.P$14 (14)
unnamed: C3.1, U$1.P$8 (8), U$1.P$16 (16)
unnamed: C3.2, Q1.3 (D), U$1.P$1 (1)
RX: J1.3, U1.8 (PB09_A7_D7_RX)
TX: J1.2, U1.7 (PB08_A6_D6_TX)

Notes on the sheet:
VCC Main
ADNS-9800
VDDIO

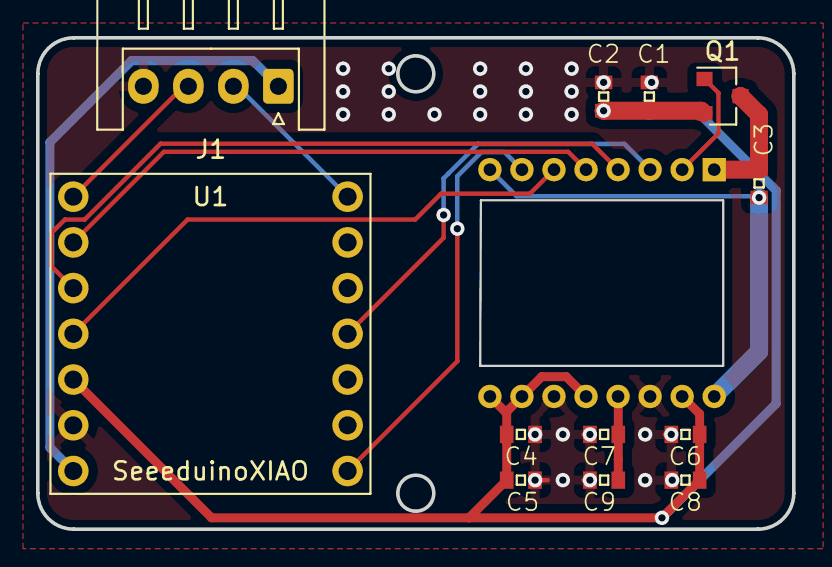
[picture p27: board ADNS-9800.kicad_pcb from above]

Board: 2 copper layers, 42.0 x 27.3 mm, 13 parts (0 on the bottom side), 14 nets.

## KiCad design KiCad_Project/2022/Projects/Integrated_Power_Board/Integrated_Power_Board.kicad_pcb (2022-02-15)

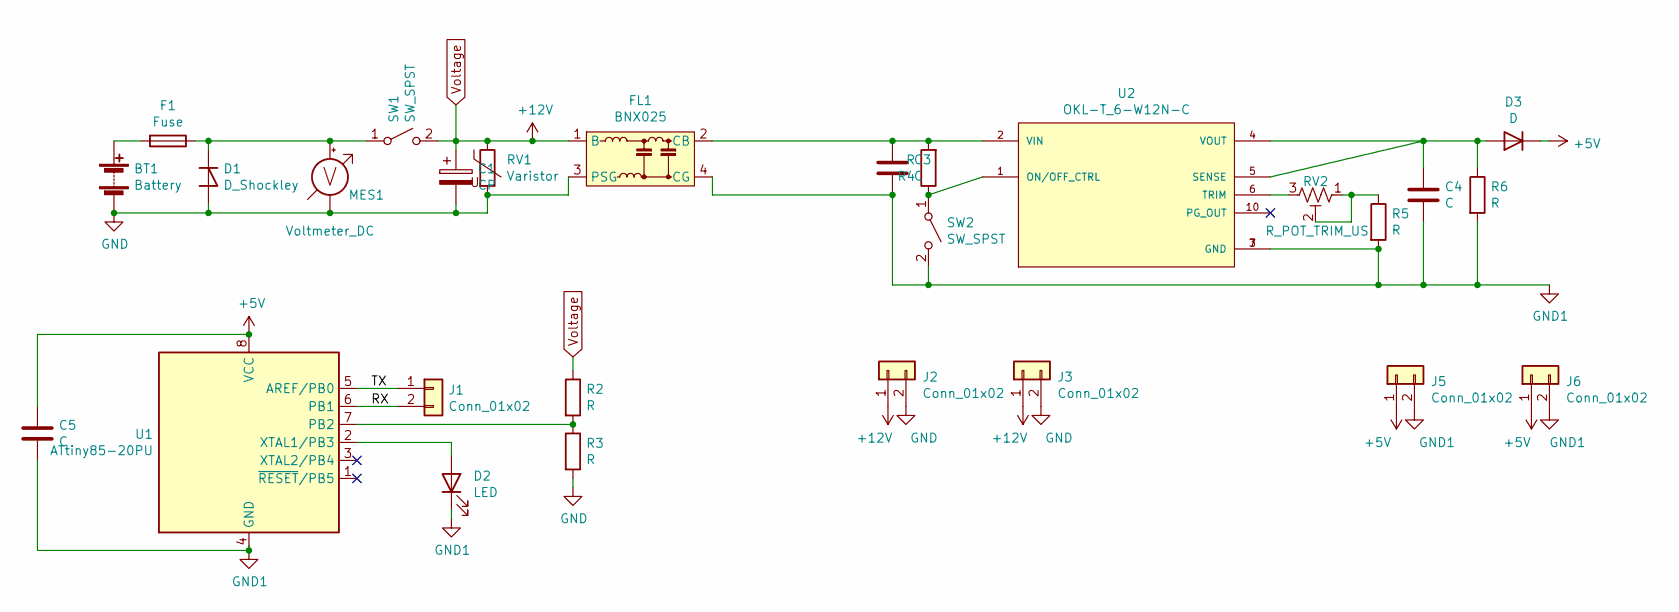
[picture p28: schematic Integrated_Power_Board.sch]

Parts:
BT1: Battery; JST_VH_B2P-VH-B_1x02_P3.96mm_Vertical
C1: CP; C_Radial_D16.0mm_H25.0mm_P7.50mm
C3, C4: C; C_Disc_D4.3mm_W1.9mm_P5.00mm
C5: C; C_Disc_D3.0mm_W1.6mm_P2.50mm
D1: D_Shockley; D_DO-201AD_P12.70mm_Horizontal
D2: LED; LED_D3.0mm_Clear
D3: D; D_DO-41_SOD81_P7.62mm_Horizontal
F1: Fuse; fuse_socket
FL1: BNX025; FIL_BNX016-01
J1, J2, J3, J5, J6: Conn_01x02; JST_XH_B2B-XH-A_1x02_P2.50mm_Vertical
MES1: Voltmeter_DC; voltage_counter
R2, R3, R4, R5, R6: R; R_Axial_DIN0207_L6.3mm_D2.5mm_P7.62mm_Horizontal
RV1: Varistor; RV_Disc_D9mm_W3.3mm_P5mm
RV2: R_POT_TRIM_US; Potentiometer_Bourns_3296W_Vertical
SW1: SW_SPST; DS-850k
SW2: SW_SPST; toggleswitch
U1: ATtiny85-20PU; DIP-8_W7.62mm
U2: OKL-T_6-W12N-C; DCDC-murata-6A

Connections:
+5V: C5.1, D3.1 (K), J5.1, J6.1, U1.8 (VCC)
/RX: J1.2, U1.6 (PB1)
/TX: J1.1, U1.5 (AREF/PB0)
GND: BT1.1 (-), C1.2, D1.2 (A), FL1.3 (PSG), J2.2, J3.2, MES1.1 (-), R3.2, RV1.2
GND1: C3.2, C4.2, C5.2, D2.1 (K), FL1.4 (CG), J5.2, J6.2, R5.2, R6.2, SW2.2 (B), U1.4 (GND), U2.3 (GND), U2.7 (GND)
unnamed: BT1.2 (+), F1.2
unnamed: C3.1, FL1.2 (CB), R4.2, U2.2 (VIN)
unnamed: C4.1, D3.2 (A), R6.1, U2.4 (VOUT), U2.5 (SENSE)
unnamed: D1.1 (K), F1.1, MES1.2 (+), SW1.1 (A)
unnamed: D2.2 (A), U1.2 (XTAL1/PB3)
unnamed: R2.2, R3.1, U1.7 (PB2)
unnamed: R4.1, SW2.1 (A), U2.1 (ON/OFF_CTRL)
unnamed: R5.1, RV2.1, RV2.2
unnamed: RV2.3, U2.6 (TRIM)
Voltage: C1.1, FL1.1 (B), J2.1, J3.1, R2.1, RV1.1, SW1.2 (B)

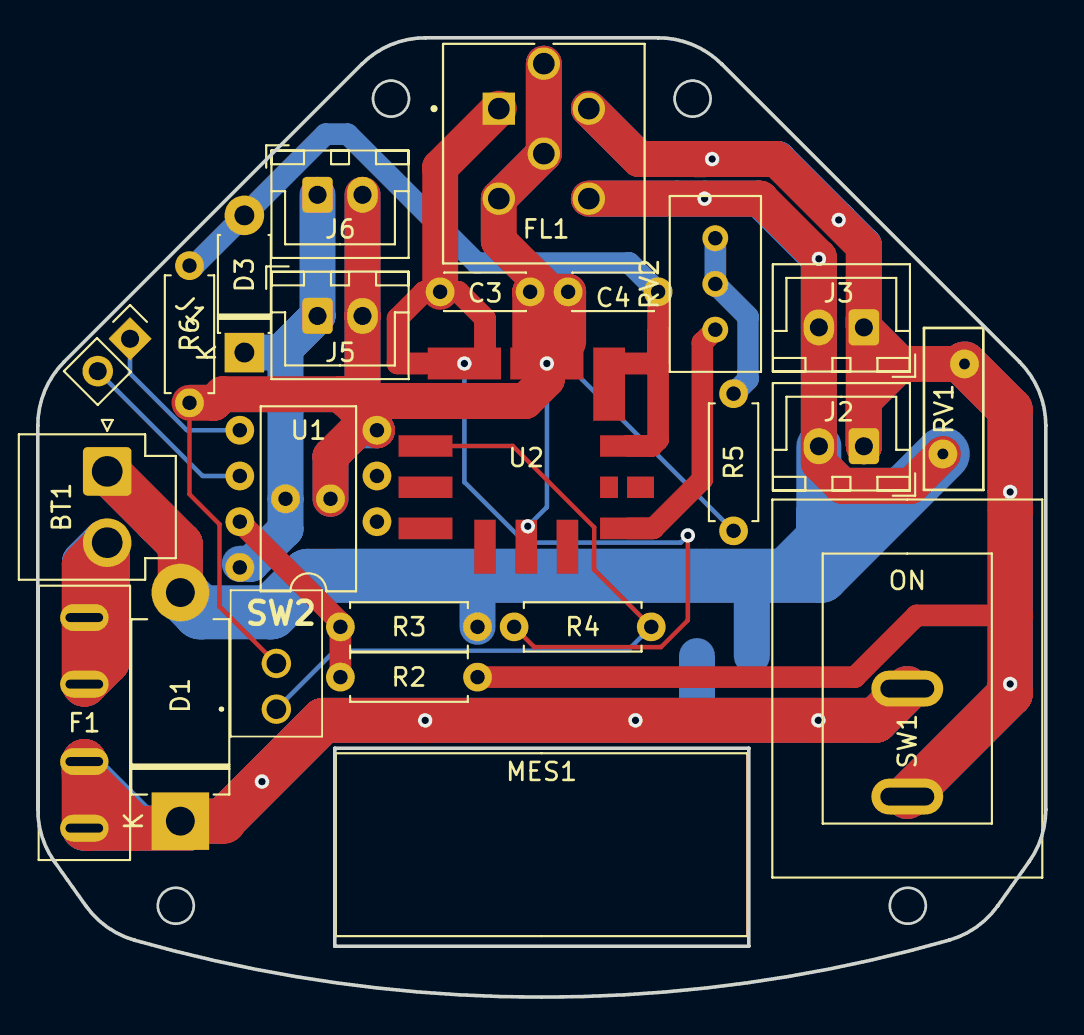
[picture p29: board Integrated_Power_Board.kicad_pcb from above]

Board: 2 copper layers, 56.0 x 53.3 mm, 25 parts (1 on the bottom side), 14 nets.

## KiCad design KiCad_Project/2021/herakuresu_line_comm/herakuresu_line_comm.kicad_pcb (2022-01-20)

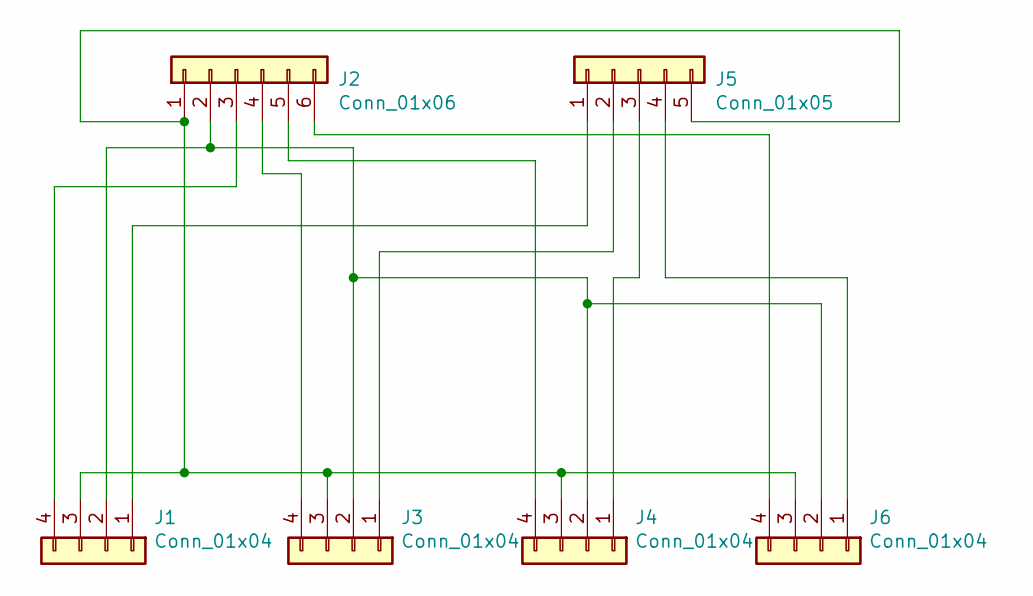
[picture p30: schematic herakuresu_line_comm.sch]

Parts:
J1, J3, J4, J6: Conn_01x04; PinHeader_1x04_P2.54mm_Vertical
J2: Conn_01x06; JST_XH_B6B-XH-A_1x06_P2.50mm_Vertical
J5: Conn_01x05; JST_XH_B5B-XH-A_1x05_P2.50mm_Vertical

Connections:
unnamed: J1.1, J5.1
unnamed: J1.2, J2.2, J3.2, J4.2, J6.2
unnamed: J1.3, J2.1, J3.3, J4.3, J5.5, J6.3
unnamed: J1.4, J2.3
unnamed: J2.4, J3.4
unnamed: J2.5, J4.4
unnamed: J2.6, J6.4
unnamed: J3.1, J5.2
unnamed: J4.1, J5.3
unnamed: J5.4, J6.1

Board: 2 copper layers, 6 parts (0 on the bottom side), 10 nets, no tracks yet.

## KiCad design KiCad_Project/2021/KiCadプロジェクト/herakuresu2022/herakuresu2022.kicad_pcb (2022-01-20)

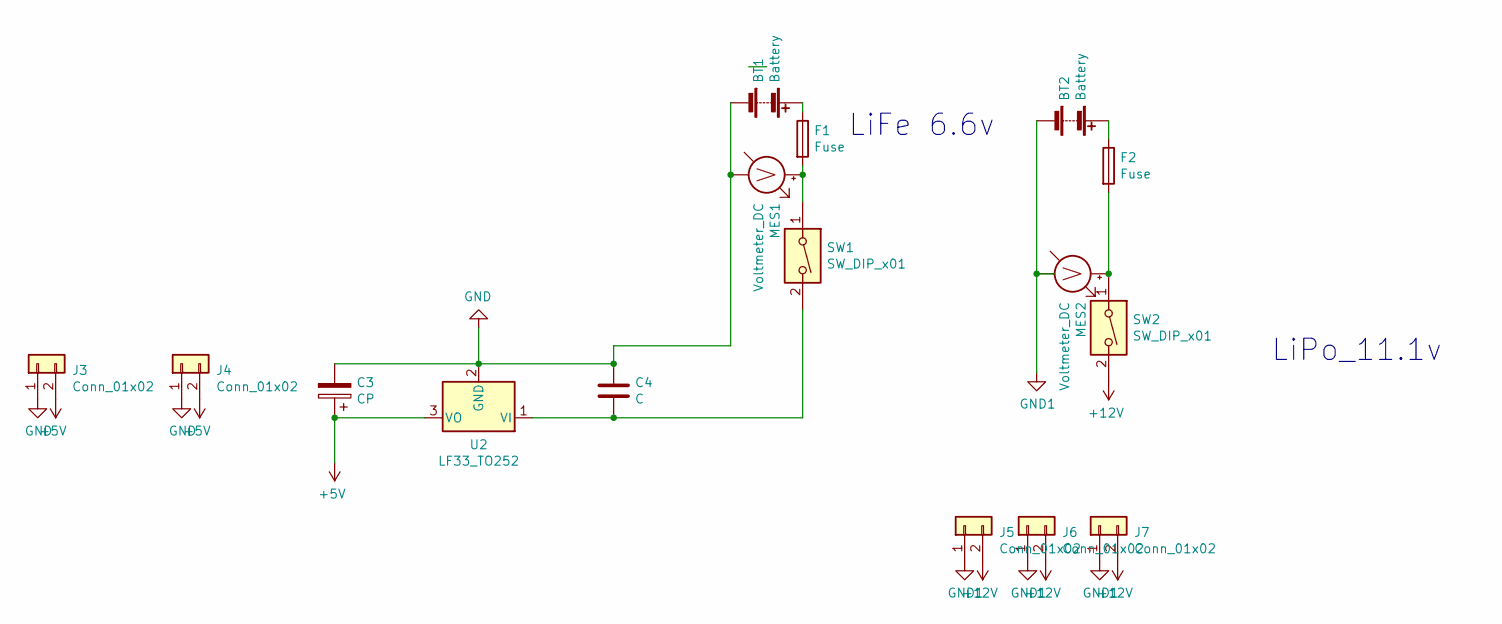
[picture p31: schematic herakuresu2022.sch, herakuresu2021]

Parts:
BT1: Battery; JST_XH_B2B-XH-A_1x02_P2.50mm_Vertical
BT2: Battery; JST_VH_B2P-VH-FB-B_1x02_P3.96mm_Vertical
C3: CP; C_Radial_D6.3mm_H11.0mm_P2.50mm
C4: C; C_Disc_D3.0mm_W2.0mm_P2.50mm
F1, F2: Fuse; fuse_socket
J3, J4, J5, J6, J7: Conn_01x02; JST_XH_B2B-XH-A_1x02_P2.50mm_Vertical
MES1, MES2: Voltmeter_DC; voltage_counter
SW1, SW2: SW_DIP_x01; 2MS1T2B4M2QES
U2: LF33_TO252; TO-262-3_Vertical

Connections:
+5V: C3.1, J3.2, J4.2, U2.3 (VO)
+12V: J5.2, J6.2, J7.2, SW2.2
GND: BT1.1 (-), C3.2, C4.1, J3.1, J4.1, MES1.1 (-), U2.2 (GND)
GND1: BT2.1 (-), J5.1, J6.1, J7.1, MES2.1 (-)
unnamed: BT1.2 (+), F1.1
unnamed: BT2.2 (+), F2.1
unnamed: C4.2, SW1.2, U2.1 (VI)
unnamed: F1.2, MES1.2 (+), SW1.1
unnamed: F2.2, MES2.2 (+), SW2.1

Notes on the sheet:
LiFe 6.6v
LiPo_11.1v

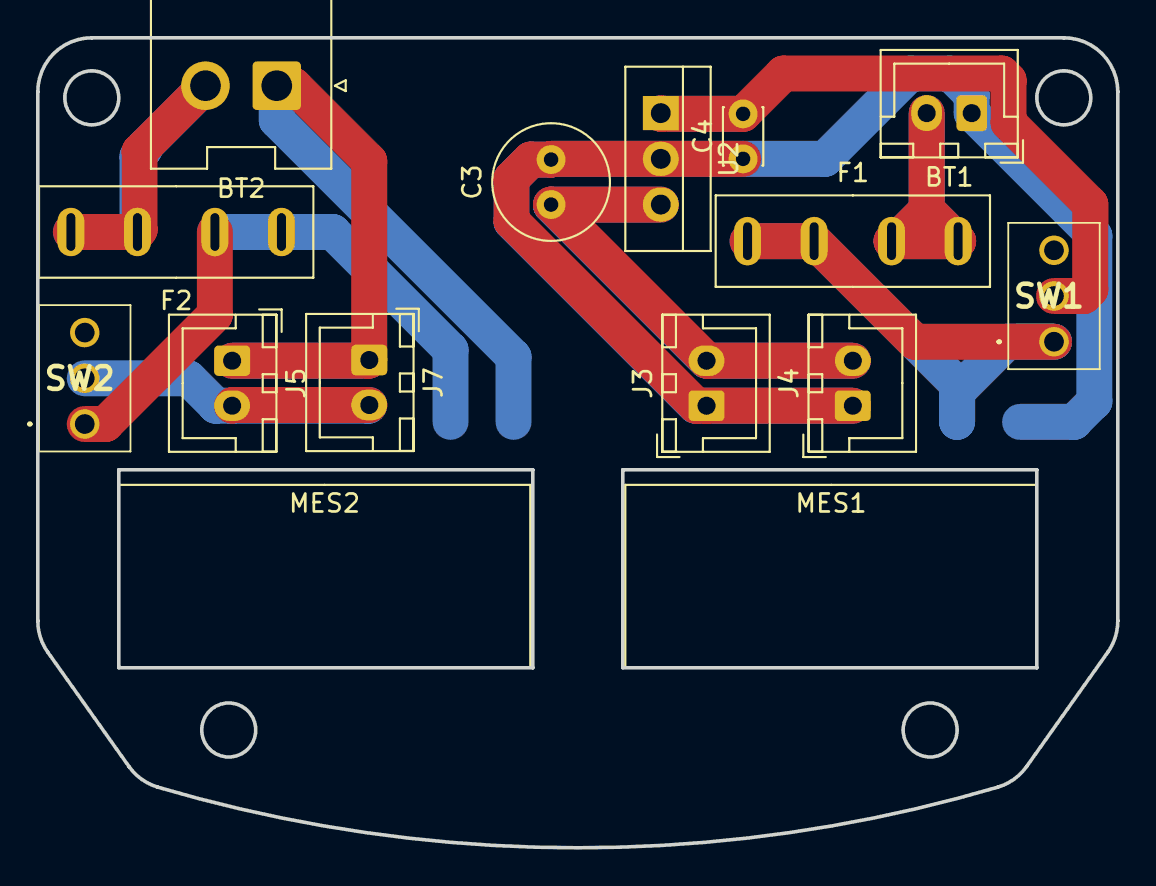
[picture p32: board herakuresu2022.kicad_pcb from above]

Board: 2 copper layers, 60.0 x 45.0 mm, 15 parts (0 on the bottom side), 9 nets.

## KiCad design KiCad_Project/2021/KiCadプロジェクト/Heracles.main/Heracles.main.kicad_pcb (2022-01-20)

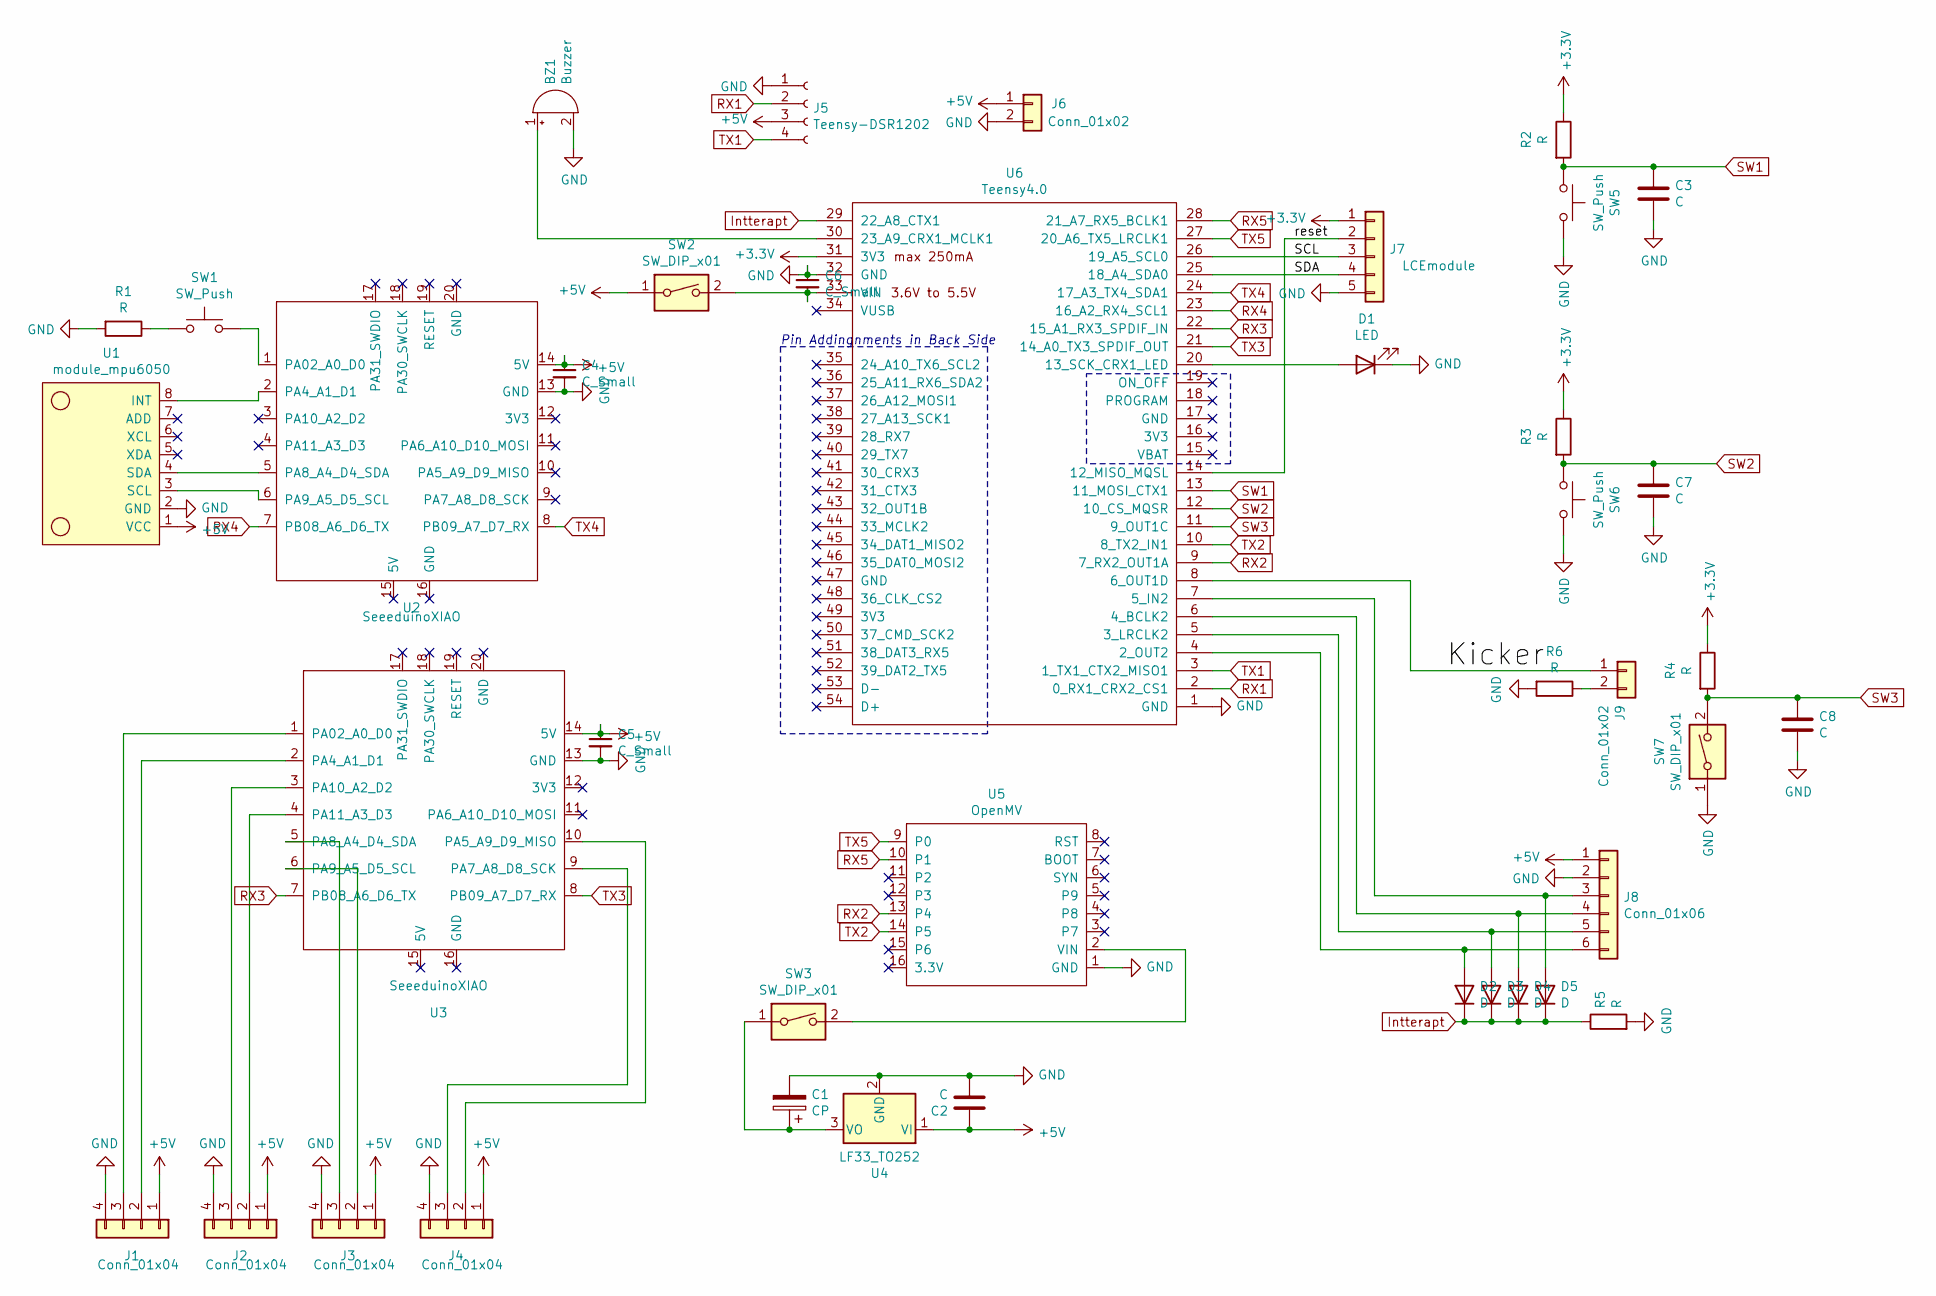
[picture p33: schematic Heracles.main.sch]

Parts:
BZ1: Buzzer; Buzzer_15x7.5RM7.6
C1: CP; C_Radial_D6.3mm_H11.0mm_P2.50mm
C2, C3, C7, C8: C; C_Disc_D3.0mm_W2.0mm_P2.50mm
C4, C5, C6: C_Small; C_Disc_D3.0mm_W2.0mm_P2.50mm
D1: LED; LED_D3.0mm_Clear
D2, D3, D4, D5: D; D_DO-41_SOD81_P7.62mm_Horizontal
J1, J2, J3, J4: Conn_01x04; JST_XH_B4B-XH-A_1x04_P2.50mm_Vertical
J5: Teensy-DSR1202; JST_XH_B4B-XH-A_1x04_P2.50mm_Vertical
J6, J9: Conn_01x02; JST_XH_B2B-XH-A_1x02_P2.50mm_Vertical
J7: LCEmodule; LCDmodule
J8: Conn_01x06; JST_XH_B6B-XH-A_1x06_P2.50mm_Vertical
R1, R2, R3, R4, R5, R6: R; R_Axial_DIN0204_L3.6mm_D1.6mm_P5.08mm_Horizontal
SW1, SW5: SW_Push; SW_PUSH_6mm_H5mm
SW2, SW3, SW7: SW_DIP_x01; toggleswitch
SW6: SW_Push; PushSwitch
U1: module_mpu6050; MPU6050
U2, U3: SeeeduinoXIAO; seeeduinoXIAO
U4: LF33_TO252; TO-252-2
U5: OpenMV
U6: Teensy4.0; Teensy

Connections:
+3V3: J7.1, R2.1, R3.1, R4.1, U6.31 (3V3)
+5V: C2.1, C4.1, C5.1, J1.1, J2.1, J3.1, J4.1, J5.3, J6.1, J8.1, SW2.1, U1.1 (VCC), U2.14 (5V), U3.14 (5V), U4.1 (VI)
/Kicker: J9.1, U6.8 (6_OUT1D)
/SCL: J7.3, U6.26 (19_A5_SCL0)
/SDA: J7.4, U6.25 (18_A4_SDA0)
/reset: J7.2, U6.14 (12_MISO_MQSL)
GND: BZ1.2 (+), C1.2, C2.2, C3.2, C4.2, C5.2, C6.1, C7.2, C8.2, D1.1 (K), J1.4, J2.4, J3.4, J4.4, J5.1, J6.2, J7.5, J8.2, R1.2, R5.2, R6.2, SW5.2, SW6.2, SW7.1, U1.2 (GND), U2.13 (GND), U3.13 (GND), U4.2 (GND), U5.1 (GND), U6.1 (GND), U6.32 (GND)
Intterapt: D2.1 (K), D3.1 (K), D4.1 (K), D5.1 (K), R5.1, U6.29 (22_A8_CTX1)
unnamed: BZ1.1 (-), U6.30 (23_A9_CRX1_MCLK1)
unnamed: C1.1, SW3.1, U4.3 (VO)
unnamed: C6.2, SW2.2, U6.33 (VIN)
unnamed: D1.2 (A), U6.20 (13_SCK_CRX1_LED)
unnamed: D2.2 (A), J8.6, U6.4 (2_OUT2)
unnamed: D3.2 (A), J8.5, U6.5 (3_LRCLK2)
unnamed: D4.2 (A), J8.4, U6.6 (4_BCLK2)
unnamed: D5.2 (A), J8.3, U6.7 (5_IN2)
unnamed: J1.2, U3.2 (PA4_A1_D1)
unnamed: J1.3, U3.1 (PA02_A0_D0)
unnamed: J2.2, U3.4 (PA11_A3_D3)
unnamed: J2.3, U3.3 (PA10_A2_D2)
unnamed: J3.2, U3.6 (PA9_A5_D5_SCL)
unnamed: J3.3, U3.5 (PA8_A4_D4_SDA)
unnamed: J4.2, U3.10 (PA5_A9_D9_MISO)
unnamed: J4.3, U3.9 (PA7_A8_D8_SCK)
unnamed: J9.2, R6.1
unnamed: R1.1, SW1.1
unnamed: SW1.2, U2.1 (PA02_A0_D0)
unnamed: SW3.2, U5.2 (VIN)
unnamed: U1.3 (SCL), U2.6 (PA9_A5_D5_SCL)
unnamed: U1.4 (SDA), U2.5 (PA8_A4_D4_SDA)
unnamed: U1.8 (INT), U2.2 (PA4_A1_D1)
RX1: J5.2, U6.2 (0_RX1_CRX2_CS1)
RX2: U5.13 (P4), U6.9 (7_RX2_OUT1A)
RX3: U3.7 (PB08_A6_D6_TX), U6.22 (15_A1_RX3_SPDIF_IN)
RX4: U2.7 (PB08_A6_D6_TX), U6.23 (16_A2_RX4_SCL1)
RX5: U5.10 (P1), U6.28 (21_A7_RX5_BCLK1)
SW1: C3.1, R2.2, SW5.1, U6.13 (11_MOSI_CTX1)
SW2: C7.1, R3.2, SW6.1, U6.12 (10_CS_MQSR)
SW3: C8.1, R4.2, SW7.2, U6.11 (9_OUT1C)
TX1: J5.4, U6.3 (1_TX1_CTX2_MISO1)
TX2: U5.14 (P5), U6.10 (8_TX2_IN1)
TX3: U3.8 (PB09_A7_D7_RX), U6.21 (14_A0_TX3_SPDIF_OUT)
TX4: U2.8 (PB09_A7_D7_RX), U6.24 (17_A3_TX4_SDA1)
TX5: U5.9 (P0), U6.27 (20_A6_TX5_LRCLK1)

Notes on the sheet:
Pin Addingnments in Back Side

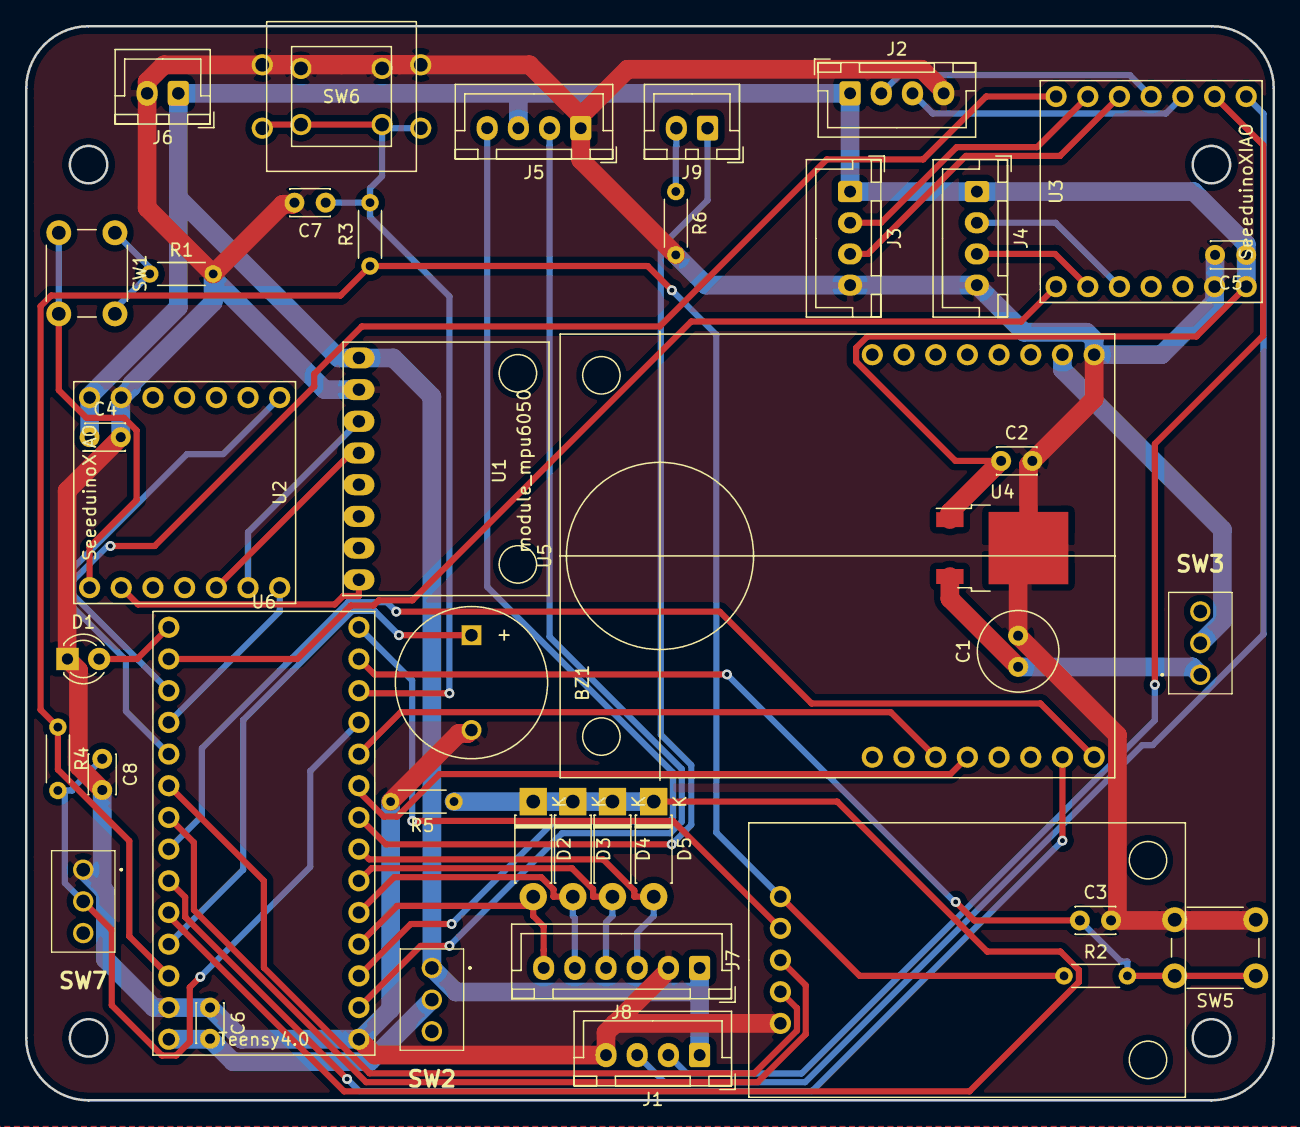
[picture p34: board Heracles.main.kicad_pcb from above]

Board: 2 copper layers, 100.0 x 86.1 mm, 41 parts (0 on the bottom side), 44 nets.

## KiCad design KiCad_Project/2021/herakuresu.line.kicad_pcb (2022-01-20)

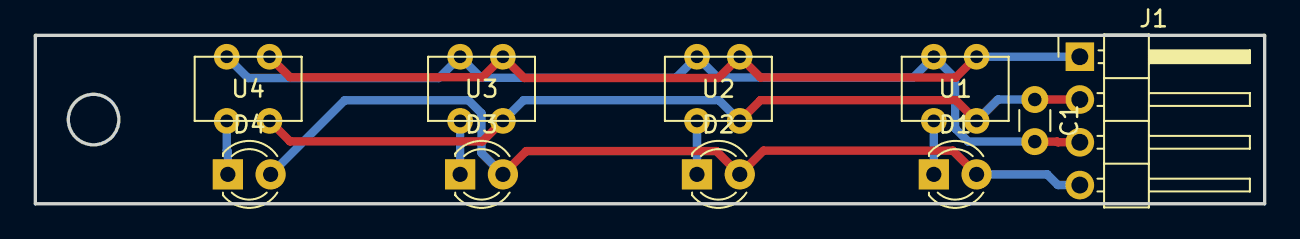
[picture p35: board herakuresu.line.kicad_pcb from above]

Board: 2 copper layers, 73.0 x 10.0 mm, 10 parts (0 on the bottom side), 8 nets.

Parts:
C1: C; C_Disc_D3.0mm_W1.6mm_P2.50mm
D1, D2, D3, D4: LED; LED_D3.0mm_Clear
J1: Conn_01x04_Female; PinHeader_1x04_P2.54mm_Horizontal
U1, U2, U3, U4: S4282; S428

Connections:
+5V: C1.1, J1.2, U1.2, U2.2, U3.2, U4.2
GND: C1.2, J1.3, U1.4, U2.4, U3.4, U4.4
LED: D1.2, D2.2, D3.2, D4.2, J1.4
unnamed: D1.1, U1.1
unnamed: D2.1, U2.1
unnamed: D3.1, U3.1
unnamed: D4.1, U4.1
Vout: J1.1, U1.3, U2.3, U3.3, U4.3

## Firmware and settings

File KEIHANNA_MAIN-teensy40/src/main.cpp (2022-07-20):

//ライブラリ読み込み
#include <Arduino.h>
#include <DSR1202.h>
#include <U8g2lib.h>

//ライブラリセットアップ
DSR1202 dsr1202(1);

//AQM1248Aは128 * 48
U8G2_ST7565_AK_AQM1248_F_4W_HW_SPI u8g2(U8G2_R0, 10, 34, 35); //CS, DC(RS), Reset(適当)

//定数置き場
#define buzzer 33 //圧電ブザー
#define button_LCD_R 27 //タクトスイッチ(右)
#define button_LCD_L 32 //タクトスイッチ(左)
#define switch_program 31  //トグルスイッチ
#define button_LCD_C 30 //タクトスイッチ(コマンド)
#define LINE_1 2  //前
#define LINE_2 3  //右
#define LINE_3 4  //後
#define LINE_4 5  //左
#define LED 9

//グローバル変数置き場(本当は減らしたいけど初心者なので当分このまま)
int head_CAM, CAM_angle, CAM_distance, CAM_YellowAngle, CAM_BlueAngle;  //OpenMVから受け取るデータ用
int head_USS, USS, USS1, USS2, USS3, USS4;  //USSから受け取るデータ用
int IMU; //IMU値
int head_BT, BT_Angle, BT_Power; //無線機

class Status {
public:
  int val, old_val;
  int state;
};

class Timer {
public:
  unsigned long timer, timer_start;
};

Status LCD, LCD_R, LCD_L, LCD_C;
Timer LINE, position, Ball;

int val_I;
int deviation, old_deviation, val_D;
float operation_A, operation_B, operation_C;

int motor[4]; //モーター出力(前向いてるときの各モーターの出力値設定)
int MotorPower[4];  //最終操作量(方向修正による操作量を含めた最終モーター出力値)

//ヘッダファイル読み込み
#include "Serial_receive.h"
#include "print_LCD.h"
#include "pid_parameter.h"
#include "pid.h"
#include "motor.h"

void setup() {
  tone(buzzer, 1568, 100);  //通電確認音

  u8g2.begin(); //LCD初期化
  u8g2.setFlipMode(1);  //反転は1(通常表示は0)

  u8g2.clearBuffer(); //内部メモリクリア(毎回表示内容更新前に置く)
  u8g2.setFont(u8g2_font_ncenB14_tr);	//フォント選択(これは横に14ピクセル、縦に14ピクセル)
  u8g2.drawStr(0,31,"Hello World!");	//書き込み内容書くところ(画面左端から横に何ピクセル、縦に何ピクセルか指定。ちなみに、文字の左下が指示座標になる。)
  u8g2.sendBuffer();  //ディスプレイに送る(毎回書く)


  //各ピン設定開始
  pinMode(button_LCD_R, INPUT);
  pinMode(button_LCD_L, INPUT);
  pinMode(button_LCD_C, INPUT);
  pinMode(switch_program, INPUT);
  pinMode(LINE_1, INPUT);
  pinMode(LINE_2, INPUT);
  pinMode(LINE_3, INPUT);
  pinMode(LINE_4, INPUT);

  dsr1202.Init(); //MD準備(USBシリアルも同時開始)
  
  Serial2.begin(115200);  //OpenMVとのシリアル通信
  Serial3.begin(115200);  //USSとのシリアル通信
  Serial4.begin(115200);  //IMUとのシリアル通信
  Serial5.begin(115200);  //M5Stamp Picoとの通信
  
  //tone(buzzer, 2093, 100);  //起動確認音

  /*Adventurer 3 Lite
  tone(buzzer, 1047, 1000); //ド6
  delay(1000);
  noTone(buzzer);
  delay(250);
  tone(buzzer, 1319, 150); //ミ6
  delay(150);
  noTone(buzzer);
  delay(100);
  tone(buzzer, 1397, 250); //ファ6
  delay(250);
  noTone(buzzer);
  delay(150);
  tone(buzzer, 1568, 150); //ソ6
  delay(150);
  noTone(buzzer);
  delay(100);
  tone(buzzer, 1760, 300); //ラ6
  delay(300);
  noTone(buzzer);
  delay(100);
  tone(buzzer, 1568, 250); //ソ6
  delay(250);
  noTone(buzzer);
  delay(200);
  tone(buzzer, 1568, 250); //ソ6
  delay(250);
  noTone(buzzer);
  delay(200);
  tone(buzzer, 2093, 250); //ド7
  delay(250);
  noTone(buzzer);
  */
}

void loop() {
  Serial_receive();
  pid();
  if ((LCD.state == 0) && (LCD_C.state == 1) && (digitalRead(switch_program) == LOW)) {
    LINE.timer = millis() - LINE.timer_start;
    if (LINE.timer < 150) {
      if (IMU == 10) {
        LINE.timer = 300;
        goto Ball;  //Ballラベルまで飛ぶ
      }
      Move(0, 0);
    } else if (LINE.timer < 300) {
      if (IMU == 10) {
        LINE.timer = 300;
        goto Ball;  //上に同じ
      }
      Motor(USS);
    } else {
      if ((digitalRead(LINE_1) == LOW) || (digitalRead(LINE_2) == LOW) || (digitalRead(LINE_4) == LOW)) {
        if (USS == 10) {
          goto Ball;  //上に同じ
        }
        for (size_t i = 0; i < 10; i++) {
          Serial1.println("1R0002R0003R0004R000");
        }
        LINE.timer_start = millis();
      } else {
        Ball: //超音波のパターン次第でライン見ずにここまで飛ぶ
        if (CAM_distance > 0) {
          position.timer = millis();
          position.timer_start = position.timer;
          Ball.timer = millis() - Ball.timer_start;
          if (Ball.timer <= 500) { //標準速度
            if (CAM_distance <= 52) {
              if (CAM_angle <= 20) {
                Move(CAM_angle, motor_speed);
              } else if (CAM_angle <= 180) {
                Move((CAM_angle + 90), motor_speed);
                Ball.timer_start = millis();
              } else if (CAM_angle < 340) {
                Move((CAM_angle - 90), motor_speed);
                Ball.timer_start = millis();
              } else {
                Move(CAM_angle, motor_speed);
              }
            } else {
              Move(CAM_angle, motor_speed);
              Ball.timer_start = millis();
            }
          } else {  //マキシマムモード(一定時間経過後パワーを上げる)
            if (CAM_distance <= 52) {
              if (CAM_angle <= 20) {
                Move(CAM_angle, (motor_speed + 3));
              } else if (CAM_angle <= 180) {
                Move((CAM_angle + 90), motor_speed);
                Ball.timer_start = millis();
              } else if (CAM_angle < 340) {
                Move((CAM_angle - 90), motor_speed);
                Ball.timer_start = millis();
              } else {
                Move(CAM_angle, (motor_speed + 3));
              }
            } else {
              Move(CAM_angle, motor_speed);
              Ball.timer_start = millis();
            }
          }
        } else {
          position.timer = millis() - position.timer_start;
          if (position.timer < 2000) {
            Move(0, 0);
          } else {
            if (USS3 > 50) {
              if (USS2 < 70) {
                if (USS4 < 70) {
                  Motor(3);  //後
                } else {
                  Motor(9);  //右後
                }
              } else if (USS4 < 70) {
                Motor(8);  //左後
              } else {
                Motor(3);  //後
              }
            } else if (USS2 < 70) {
              if (USS4 < 70) {
                Motor(1);  //方向修正
              } else {
                Motor(5);  //右
              }
            } else if (USS4 < 70) {
              Motor(4);  //左
            } else {
              Motor(1);  //方向修正
            }
          }
        }
      }
    }
  } else if ((LCD.state == 7) && (LCD_C.state == 1) && (digitalRead(switch_program) == LOW)) {
    Move(0, 0);
  } else if ((LCD.state == 8) && (LCD_C.state == 1) && (digitalRead(switch_program) == LOW)) {
    Move(BT_Angle, BT_Power);
  } else {
    print_LCD();
    dsr1202.move(0, 0, 0, 0);
  }
}

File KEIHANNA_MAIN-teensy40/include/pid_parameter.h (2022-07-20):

#define IMU_center 90 //ジャイロ中心値
#define gain_P 1.14  //比例ゲイン
#define gain_I 0.00  //積分ゲイン
#define gain_D 119.93  //微分ゲイン

#define set_limit_operation 20  //操作量限界値(絶対値)
#define motor_speed 29  //モーター速度(絶対値)
#define motor_limit 40  //モーター速度限界値(絶対値)

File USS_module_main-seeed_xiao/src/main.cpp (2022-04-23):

#include <Arduino.h>

#define echoPin1 2  //  前超音波のechoピン
#define trigPin1 3  //  前超音波のトリガー
#define echoPin2 4  //  左超音波のechoピン
#define trigPin2 5  //  左超音波のトリガー
#define echoPin3 0  //  後超音波のechoピン
#define trigPin3 1  //  後超音波のトリガー
#define echoPin4 8  //  右超音波のechoピン
#define trigPin4 9  //  右超音波のトリガー
#define LED 13  //LEDピン

#define val 30.00

class ClassA {
private:
  
public:
  double Duration = 0;
  double Distance = 0;
};

ClassA front, left, back, right;

int timeout = 20000; //タイムアウト設定値(マイクロ秒)

void setup() {
  pinMode(echoPin1, INPUT);
  pinMode(trigPin1, OUTPUT);
  pinMode(echoPin2, INPUT);
  pinMode(trigPin2, OUTPUT);
  pinMode(echoPin3, INPUT);
  pinMode(trigPin3, OUTPUT);
  pinMode(echoPin4, INPUT);
  pinMode(trigPin4, OUTPUT);
  pinMode(LED, OUTPUT);

  Serial.begin(115200); //USBシリアル通信開始
  Serial1.begin(115200);  //Teensyとの接続開始

  while (!Serial1) {
    ; //Teensyとの接続待機
  }

}

void loop() {
  digitalWrite(LED, HIGH); //動作確認用LED処理

  digitalWrite(trigPin1, LOW);  //パスル出力準備
  delayMicroseconds(2);

  digitalWrite(trigPin1, HIGH); //パルス出力処理
  delayMicroseconds(10);  //モジュールごとに送信時間要確認

  digitalWrite(trigPin1, LOW);  //パスル出力終了処理

  front.Duration = pulseIn(echoPin1, HIGH, timeout); //パスル確認処理

  if (front.Duration > 0) {  //前超音波
    front.Duration = front.Duration / 2;
    front.Distance = front.Duration * 340 * 100 / 1000000;

  }

  if (front.Distance >= 254) {
    front.Distance = 254;

  }
  
  Serial.print(front.Distance);  //シリアルモニタ用
  Serial.print("\t");

  digitalWrite(LED, LOW);  //動作確認用LED処理

  digitalWrite(trigPin2, LOW);  //パスル出力準備
  delayMicroseconds(2);

  digitalWrite(trigPin2, HIGH); //パスル出力処理
  delayMicroseconds(10);  //モジュールごとに要確認

  digitalWrite(trigPin2, LOW);  //パスル出力終了処理

  left.Duration = pulseIn(echoPin2, HIGH, timeout); //パスル確認処理

  if (left.Duration > 0) {  //左超音波
    left.Duration = left.Duration / 2;
    left.Distance = left.Duration * 340 * 100 / 1000000;

  }

  if (left.Distance >= 254) {
    left.Distance = 254;

  }

  Serial.print(left.Distance);  //シリアルモニタ用
  Serial.print("\t");

  digitalWrite(LED, HIGH); //動作確認用LED処理

  digitalWrite(trigPin3, LOW);  //パスル出力準備
  delayMicroseconds(2);

  digitalWrite(trigPin3, HIGH); //パスル出力処理
  delayMicroseconds(10);  //モジュールごとに要確認

  digitalWrite(trigPin3, LOW);  //パスル出力終了処理

  back.Duration = pulseIn(echoPin3, HIGH, timeout); //パスル確認処理

  if (back.Duration > 0) {  //後超音波
    back.Duration = back.Duration / 2;
    back.Distance = back.Duration * 340 * 100 / 1000000;

  }

  if (back.Distance >= 254) {
    back.Distance = 254;

  }

  Serial.print(back.Distance);  //シリアルモニタ用
  Serial.print("\t");

  digitalWrite(LED, LOW);  //動作確認用LED処理

  digitalWrite(trigPin4, LOW);  //パスル出力準備
  delayMicroseconds(2);

  digitalWrite(trigPin4, HIGH); //パスル出力処理
  delayMicroseconds(10);  //モジュールごとに要確認

  digitalWrite(trigPin4, LOW);  //パスル出力終了処理

  right.Duration = pulseIn(echoPin4, HIGH, timeout); //パスル確認処理

  if (right.Duration > 0) {  //右超音波
    right.Duration = right.Duration / 2;
    right.Distance = right.Duration * 340 * 100 / 1000000;

  }

  if (right.Distance >= 254) {
    right.Distance = 254;

  }

  Serial.println(right.Distance);  //シリアルモニタ用

  Serial1.write(255);
  
  if (front.Distance < val) {
    if (left.Distance < val) {
      if (back.Distance < val) {
        if (right.Distance < val) {
          Serial1.write(1); //停止

        } else {
          Serial1.write(5); //右

        }
      } else if (right.Distance < val) {
        Serial1.write(3); //後

      } else {
        Serial1.write(9); //右後

      }
    } else if (back.Distance < val) {
      if (right.Distance < val) {
        Serial1.write(4); //左

      } else {
        Serial1.write(1); //停止

      }
    } else if (right.Distance < val) {
      Serial1.write(8); //左後

    } else {
      Serial1.write(3); //後

    }
  } else if (left.Distance < val) {
    if (back.Distance < val) {
      if (right.Distance < val) {
        Serial1.write(2); //前

      } else {
        Serial1.write(7); //右前

      }
    } else if (right.Distance < val) {
      Serial1.write(1); //停止

    } else {
      Serial1.write(5); //右

    }
  } else if (back.Distance < val) {
    if (right.Distance < val) {
      Serial1.write(6); //左前

    } else {
      Serial1.write(2); //前

    }
  } else if (right.Distance < 35.00) {
    Serial1.write(4); //左

  } else {
    Serial1.write(10); //停止

  }

  Serial1.write(front.Distance);
  Serial1.write(left.Distance);
  Serial1.write(back.Distance);
  Serial1.write(right.Distance);

  Serial1.flush();
}

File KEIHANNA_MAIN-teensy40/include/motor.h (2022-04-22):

void Motor(int direction) {
  switch (direction) {
    case 1:
      motor[0] = 0;  //右前
      motor[1] = 0;  //右後
      motor[2] = 0;  //左前
      motor[3] = 0;  //左後
      break;
    case 2:
      motor[0] = motor_speed;  //右前
      motor[1] = motor_speed;  //右後
      motor[2] = -motor_speed; //左前
      motor[3] = -motor_speed; //左後
      break;
    case 3:
      motor[0] = -motor_speed; //右前
      motor[1] = -motor_speed; //右後
      motor[2] = motor_speed;  //左前
      motor[3] = motor_speed;  //左後
      break;
    case 4:
      motor[0] = motor_speed;  //右前
      motor[1] = -motor_speed; //右後
      motor[2] = motor_speed;  //左前
      motor[3] = -motor_speed; //左後
      break;
    case 5:
      motor[0] = -motor_speed; //右前
      motor[1] = motor_speed;  //右後
      motor[2] = -motor_speed; //左前
      motor[3] = motor_speed;  //左後
      break;
    case 6:
      motor[0] = motor_speed;  //右前
      motor[1] = 0;  //右後
      motor[2] = 0;  //左前
      motor[3] = -motor_speed; //左後
      break;
    case 7:
      motor[0] = 0;  //右前
      motor[1] = motor_speed;  //右後
      motor[2] = -motor_speed; //左前
      motor[3] = 0;  //左後
      break;
    case 8:
      motor[0] = 0;  //右前
      motor[1] = -motor_speed; //右後
      motor[2] = motor_speed;  //左前
      motor[3] = 0;  //左後
      break;
    case 9:
      motor[0] = -motor_speed; //右前
      motor[1] = 0;  //右後
      motor[2] = 0;  //左前
      motor[3] = motor_speed;  //左後
      break;
  }

  MotorPower[0] = operation_A + motor[0];
  if (MotorPower[0] < -motor_limit) {
    MotorPower[0] = -motor_limit;
  } else if (MotorPower[0] > motor_limit) {
    MotorPower[0] = motor_limit;
  }

  MotorPower[1] = operation_A + motor[1];
  if (MotorPower[1] < -motor_limit) {
    MotorPower[1] = -motor_limit;
  } else if (MotorPower[1] > motor_limit) {
    MotorPower[1] = motor_limit;
  }

  MotorPower[2] = operation_A + motor[2];
  if (MotorPower[2] < -motor_limit) {
    MotorPower[2] = -motor_limit;
  } else if (MotorPower[2] > motor_limit) {
    MotorPower[2] = motor_limit;
  }

  MotorPower[3] = operation_A + motor[3];
  if (MotorPower[3] < -motor_limit) {
    MotorPower[3] = -motor_limit;
  } else if (MotorPower[3] > motor_limit) {
    MotorPower[3] = motor_limit;
  }

  dsr1202.move(MotorPower[0], MotorPower[1], MotorPower[2], MotorPower[3]);
}

void Move(int motor_rads, int motor_power) {
  motor[0] = motor_power * sin((motor_rads + 45) * PI / 180); //右前
  motor[1] = motor_power * cos((motor_rads + 45) * PI / 180);  //右後
  motor[2] = -motor_power * cos((motor_rads + 45) * PI / 180); //左前
  motor[3] = -motor_power * sin((motor_rads + 45) * PI / 180);  //左後

  MotorPower[0] = operation_A + motor[0];
  if (MotorPower[0] < -motor_limit) {
    MotorPower[0] = -motor_limit;
  } else if (MotorPower[0] > motor_limit) {
    MotorPower[0] = motor_limit;
  }

  MotorPower[1] = operation_A + motor[1];
  if (MotorPower[1] < -motor_limit) {
    MotorPower[1] = -motor_limit;
  } else if (MotorPower[1] > motor_limit) {
    MotorPower[1] = motor_limit;
  }

  MotorPower[2] = operation_A + motor[2];
  if (MotorPower[2] < -motor_limit) {
    MotorPower[2] = -motor_limit;
  } else if (MotorPower[2] > motor_limit) {
    MotorPower[2] = motor_limit;
  }

  MotorPower[3] = operation_A + motor[3];
  if (MotorPower[3] < -motor_limit) {
    MotorPower[3] = -motor_limit;
  } else if (MotorPower[3] > motor_limit) {
    MotorPower[3] = motor_limit;
  }

  dsr1202.move(MotorPower[0], MotorPower[1], MotorPower[2], MotorPower[3]);
}

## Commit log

2021-12-26 ふじたきよゆきが編集しました
2021-12-26 メッセージ削除
2021-12-26 スペースが増えたよ！(見づらくて草)
2021-12-26 編集してみました
2021-12-27 説明を増やしました
2021-12-27 作りかけです
2021-12-27 あとは各種モーターの値を設定してあげてください
2021-12-27 表示内容を変更しました
2021-12-27 IMUの値反転とCAM情報取得処理を追加
2021-12-27 CAMとPID制御用の変数を追加
2021-12-27 ラインやカメラ角度などのおおまかな骨組みを作成
2021-12-27 test.cppなんてなかった。いいね？
2021-12-27 テストコメントの削除
2021-12-27 スペースが減ったよ
2021-12-27 PID設定してね
2021-12-27 色々調整入れました
2021-12-27 なんちゃってクラス導入
2021-12-27 ちょっとずつ変わったで
2021-12-28 PID制御実装
2021-12-28 モーター限界値設定をMotor各関数内で行うようにしました
2021-12-28 LCD切り替えスイッチを押すと、プログラムの実行状態が必ず解除されるようになりました
2021-12-28 MD準備開始位置の変更と、OpenMVとの通信を行えるようにしました
2021-12-28 USBシリアル通信の速度を115200bpsに統一しました
2021-12-30 定位置用の情報は送らないようにしました。そして、送信が完了するまで待機するようになります。
2021-12-30 クラスにまとめました
2022-01-02 KiCadプロジェクトファイルの作成
    [KiCad_Project_main.kicad_pcb, KiCad_Project_main.sch]
2022-01-05 自分好みに変えました
2022-01-05 コメント位置が変わりました
2022-01-05 私好みになりました
2022-01-05 PIDパラメータ値をここで変えれるようにしました
2022-01-05 誤動作防止処理を追加しました
2022-01-05 クラスの表記がまとまったり、ゲイン値が消えたり
2022-01-05 ライブラリとヘッダファイルで表記を変えました
2022-01-06 コードの最適化
2022-01-06 コードの最適化(変数被りの除去)
2022-01-06 変数被り防止
2022-01-06 変数被り防止とメモリ使用量削減
2022-01-06 ピン番号の修正
2022-01-06 Source Treeテストコメントの追加
2022-01-06 テストコメント削除
2022-01-07 トグルスイッチの役割をモード固定的なものへと変更しました
2022-01-07 モーターモードに姿勢制御を実装
2022-01-07 操作量の上限値、下限値の見直し
2022-01-07 操作量上限値とモーター速度がパラメータ設定から変更可能になりました
2022-01-07 モーター速度をパラメータに置き換えました
2022-01-07 モーター速度限界値をパラメータから調整できるようになりました
2022-01-08 PID制御を一時的に外してます
2022-01-08 タイプミス修正
2022-01-08 パラメータを変数化
2022-01-08 PID制御の読み込みを一時的に外しました
2022-01-13 方向判定の変数化
2022-01-13 LCD表示バグの修正
2022-01-13 方向判定の仕様変更
2022-01-15 出力バランス調整
2022-01-15 関数呼び出し時にどの値が何なのかわかるようにコメントを追加
2022-01-16 IMU閾値を読み込み専用に変更
2022-01-18 アナログ出力分解能を変更
2022-01-19 開発間に合わないんで
2022-01-19 ミス修正とか色々
2022-01-19 走り抜けるぜッ！最後まで
2022-01-19 gotoの削除
2022-01-19 処理の仕様変更
2022-01-19 変数の追加と削除
2022-01-19 loop関数内は全て条件分岐での動作に変更
2022-01-20 回路関係のファイルをGitにまとめました
    発注ファイルとDFXでごちゃごちゃしてるのはすいません
    [2MS1T2B4M2QES.stl, 2MS1T2B4M2QES.stp, 2ms1t2b4m2qes.psm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]
2022-01-20 統合電源基板
    [BNX016-01--3DModel-STEP-1.STEP, Integrated_Power_Board.kicad_pcb, Integrated_Power_Board.sch]
2022-01-21 処理の若干の変更
2022-01-21 色々微調整
2022-01-21 nakamoto的メインプログラム
2022-01-21 ライブラリの追加
    [OKL-T_6-W12N-C.step]
2022-01-21 EMI対策とDCDCの周辺設計
    過電流保護機能・加熱保護機能付き
    可変抵抗で出力の変更可能
    [Integrated_Power_Board.sch]
2022-01-21 回路図の完成
    [Integrated_Power_Board.sch]
2022-01-22 仕様変更
2022-01-22 ラインセンサをデジタルで読むように変更
2022-01-22 IMUの範囲調整
2022-01-22 メインプログラム(仮)
2022-01-22 RCAPで開発した遺産たち
2022-01-22 MPU遺産削除
2022-01-22 MPU6050用のXiaoプログラム
2022-01-22 定位置が動作しないおそれのある不具合を修正
2022-01-22 OpenMVプログラムの移植
2022-01-22 定位置の変更
2022-01-23 九州ブロック 本番調整
2022-01-23 カメラ通信の安定化
2022-01-23 コネクタの逆差し対策
    ショットキーバリスタダイオードでDCDCよりも前に素早く短絡させます
    [Integrated_Power_Board.sch]
2022-01-24 プチ変更
2022-01-27 九州ブロックでのやつ
2022-01-29 PID制御のリベンジとクラスの追加
2022-01-29 ライブラリを初期化
2022-01-29 このリポジトリのライセンスについて
2022-02-01 電源統合基板の進捗
    [BNX016-01.step, Integrated_Power_Board.sch]
2022-02-05 Kicadプロジェクトの整理
    ファイルについて
    各基板のプロジェクト・ライブラリ・PDF・DXF・自動配線用・発注ファイル
    に分けました。
    またライブラリのインポートに際してプロフェクトからの相対パスに変更したため環境を変更しても編集することができます。
    [ADNS-9800.kicad_pcb, ADNS-9800.sch, B2B-XH-A_LF__SN_.step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]
2022-02-05 環境設定
2022-02-07 電源系の設計の完了
    ATtinyを使って電圧を測定してシリアルでメインマイコンに送信します
    レベル変換についてはまだ考えてない
    [Integrated_Power_Board.sch]
2022-02-09 部品の配置
    [Integrated_Power_Board.kicad_pcb, Integrated_Power_Board.sch]
2022-02-10 ビアを追加してノイズ対策
    [Integrated_Power_Board.kicad_pcb]
2022-02-12 統合電源基板の設計の完了
    [Integrated_Power_Board.kicad_pcb, Integrated_Power_Board.sch]
2022-02-13 設計図資料の更新と発注用ファイルの作成
    [Integrated_Power_Board.kicad_pcb, Integrated_Power_Board.sch]
2022-02-15 ごちゃごちゃ感が若干改善された
2022-02-15 回り込みの関数化
2022-02-15 積分値の初期化範囲の設定
2022-02-15 発注ファイルの設定の変更
    [Integrated_Power_Board-B_Cu.gbl, Integrated_Power_Board-B_Mask.gbs, Integrated_Power_Board-B_Paste.gbp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]
2022-02-17 視認性が向上？
2022-02-17 データの受信仕様変更
2022-02-19 メンテナンス性の向上
2022-02-19 回り込みの仕様変更とか
2022-02-24 マウスセンサの設計の完了
    ADNS－9800使用
    SeeeduinoXIAOを用いてUARTでメインマイコンと通信
    [ADNS-9800.dxf, ADNS-9800.kicad_pcb]
2022-03-01 メインボードの開発
    [Main_Board.kicad_pcb, Main_Board.kicad_sch]
2022-03-01 READMEの編集
2022-03-10 Startupをmain内に移動
2022-03-18 メインボードの進捗
    [Main_Board.kicad_pcb, Main_Board.kicad_sch, Main_Board.sch]
2022-03-19 MPU6050ジャイロ仕様変更
2022-03-19 VSCode拡張機能関係の追加
2022-03-19 PID制御をごにょごにょしたやつ
2022-03-19 PID周りをごにょごにょ
2022-03-19 変更点のコミット
2022-03-21 ライブラリの参照問題？
    [Main_Board.kicad_sch]
2022-03-22 マウス基板の改良
    [ADNS-9800.kicad_pcb, Main_Board.kicad_sch]
2022-03-22 バックアップ
2022-03-22 ライブラリの編集
2022-03-22 ライブラリの参照問題
    [Main_Board.kicad_sch, Main_Board.sch]
2022-03-22 徹夜の進捗、朝マック食べに行きます
    [ADNS-9800-B_Mask.gbs, ADNS-9800-B_Paste.gbp, ADNS-9800-B_Silkscreen.gbo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]
2022-03-23 フットプリントライブラリの編集
    [Main_Board.kicad_sch]
2022-03-25 フットプリントの割り当てまで終わった
    [Main_Board.kicad_sch]
2022-03-26 DXFの出力
    [Main_Board.dxf]
2022-03-27 PID制御のある程度の仕様固め
2022-03-27 switch caseに置き換え
2022-03-27 回り込み調整段階
2022-03-27 最終的な基板の完成
    [Main_Board-B_Cu.gbl, Main_Board-B_Mask.gbs, Main_Board-B_Paste.gbp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]
2022-03-28 レジストを抜いて文字とURLを記入
    [Main_Board-B_Cu.gbl, Main_Board-B_Mask.gbs, Main_Board-B_Paste.gbp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]
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
